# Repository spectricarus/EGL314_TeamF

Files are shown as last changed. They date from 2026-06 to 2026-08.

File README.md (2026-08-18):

# EGL314 Photobooth Project

This repository contains the Proof of Concept, MVP, and Final build
documentation and source files for the EGL314 Media Solutioning Project 1
photobooth project, built for **Project Phantom**.

The project is a self-contained digital photobooth system that combines
software, hardware, and enclosure design. The system uses a Raspberry Pi,
touchscreen display, USB webcam, OpenCV, and MediaPipe to capture a user
photo, remove the original background, replace it with a selected
background, and save the final output image. The components are contained inside a 3D-printed enclosure that is specially designed to properly mount a Raspberry Pi, a 7 inch touchscreen and a USB camera.

## How the software and hardware fit together

These are documented separately (different team members are responsible for
each), but they form one physical system:

- The **Raspberry Pi** runs the software in this repository directly —
  `finalV6.py` is the app that appears on the touchscreen.
- The **touchscreen display** is what the software's Tkinter GUI renders to.
- The **USB webcam**, mounted in the enclosure, is what the software reads
  from (`CAMERA_DEVICE` in `finalV6.py` points to it).
- The **enclosure** physically houses and positions the Pi, screen, and
  camera, and its cable routing/mounting design determines how those
  components are physically wired to each other.

## Repository Structure

```text
EGL314_TeamF/
├── README.md
├── POC/
│   ├── README.md
│   ├── CODE_STRUCTURE.md
│   ├── app.py
│   ├── style.py
│   ├── requirements.txt
│   ├── assets/
│   │   └── backgrounds/
│   ├── images/
│   └── Enclosure/
│       ├── README.md
│       ├── CAD/
│       ├── STL/
│       └── Images/
│
├── MVP/
│   ├── README.md
│   ├── Hardware/
│   └── Software/
│       ├── README.md
│       ├── finalV6.py
│       ├── style.py
│       ├── requirements.txt
│       ├── docs/
│       │   ├── CODE_STRUCTURE.md
│       │   ├── environment-setup.md
│       │   ├── dependencies.md
│       │   ├── file-connections.md
│       │   ├── pipeline-explained.md
│       │   ├── ui-flow.md
│       │   └── background-templates.md
│       └── assets/
│           ├── pipeline-diagram.svg
│           ├── screenshots/
│           └── background-templates/
│
└── Final/
    ├── README.md
    ├── Enclosure/
    │   └── README.md
    └── Software/
        ├── README.md
        ├── finalphotobooth.py
        ├── style.py
        ├── requirements.txt
        ├── docs/
        │   ├── environment-setup.md
        │   ├── dependencies.md
        │   ├── CODE_STRUCTURE.md
        │   ├── file-connections.md
        │   ├── pipeline-explained.md
        │   ├── ui-flow.md
        │   ├── background-templates.md
        │   ├── architecture.md
        │   ├── camera-reliability.md
        │   ├── download-pipeline.md
        │   ├── compositing-and-banner.md
        │   └── troubleshooting.md
        └── assets/
            ├── backgrounds/
            └── screenshots/
```

## Sections

### [`POC`](./POC)

The `POC` folder contains the software Proof of Concept for the photobooth
application — Python source code, required dependencies, and background
assets.

### [`Enclosure`](./POC/Enclosure)

Nested inside `POC`, this folder contains the physical enclosure design:
CAD files, STL files, images, and documentation for the Raspberry Pi,
touchscreen display, USB webcam, cable routing, and mounting system.

### [`MVP`](./MVP)

The `MVP` folder contains the working MVP version of the photobooth
application — the stage after Proof of Concept, split into two parts:

- [**Software**](./MVP/Software/README.md) — full documentation covering the
  code, dependencies, environment setup, a diagram of the background-removal
  pipeline and the reasoning behind it, and UI flow
- [**Hardware**](./MVP/Hardware) — enclosure and physical build for the MVP
  stage

### [`Final`](./Final)

The `Final` folder contains the finished, event-ready version of the
photobooth used for **Project Phantom** — the stage after MVP, with
reliability, performance, and experience improvements made in the final
stretch before the event.

See [`Final/README.md`](./Final/README.md) for the full picture, including
the hardware used and links into both the Software and Enclosure
documentation.

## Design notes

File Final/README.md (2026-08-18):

# Project Phantom Photobooth — Final Build

[↑ Back to repository overview](../README.md)

This is the final, event-ready version of the photobooth built for **Project Phantom** (NYP EGL314). It builds on the earlier POC and MVP stages, with a large number of reliability, performance, and experience improvements made in the final stretch before the event.

A guest walks up, gets their photo taken, sees themselves composited onto a themed background, picks their favourite, and scans a QR code to take it home — all through a touchscreen, with no need for anyone to touch a keyboard.

## Hardware — the shared foundation for both Enclosure and Software

This section lives here, at the top level, deliberately — it isn't really an "enclosure thing" or a "software thing," it's context both halves of this documentation depend on. The enclosure needs to physically fit around this exact hardware (cutout sizes, screw mounts, cable routing); the software is written assuming these exact components and their specific capabilities. If any of these get swapped for a different model later, both sides of the documentation may need re-checking against the real thing.

**Required:**

| Component | Notes |
|---|---|
| **Raspberry Pi 4 Model B** | The computer running everything |
| **Raspberry Pi 7" touchscreen display** | The official Raspberry Pi touchscreen — what the guest sees and taps |
| **Display ribbon cable** | Connects the touchscreen to the Pi — its length and routing is a real constraint on the enclosure's internal layout |
| **Logitech BRIO 4K USB webcam** | Takes the photo. The software is written around this specific camera's capabilities (resolution, supported frame rates) — see the [Software docs](./Software/docs/camera-reliability.md) for why the exact camera matters more than you'd expect |
| **DFRobot Gravity Digital Speaker Module (SKU: FIT0449)** | Plays the countdown beeps and confirmation sounds, wired to a GPIO pin on the Pi |
| **32GB microSD card** | Holds the OS and everything the software needs to run |
| **Jumper wires and power supply** | Wiring the speaker to the Pi, and powering the whole thing |

**Optional (improves photo quality, not required for the booth to function):**

| Component | Notes |
|---|---|
| **Two studio-style LED light panels with stands** | Gives even, flattering lighting on the guest. Any reasonably even light source works — dedicated panels just do it noticeably better than ambient room lighting alone |

**Also required, but not a physical component: a wifi connection.** The software uploads each finished photo to Google Drive and generates a QR code linking to it, so the guest can get the photo on their own phone — this requires an active internet connection at the point of upload. Without wifi, photos can still be taken and previewed, but the download/QR step won't work. See the [download pipeline docs](./Software/docs/download-pipeline.md) for how this upload actually works.

None of this is exotic hardware — it's a fairly standard "Raspberry Pi + touchscreen + webcam" kiosk setup, just with the specific models above.

## Where to go from here

This documentation is split into two parts, matching the two halves of the actual physical build, both of which build on the hardware above:

- **[Enclosure](./Enclosure/README.md)** — the physical housing/case the electronics live inside.
- **[Software](./Software/README.md)** — everything that makes the booth actually work: the code, how to set it up, and how it's built.

## A quick note on how this documentation works

Each section starts with a plain-language overview that assumes no prior knowledge — you should be able to read just the top of each page and understand what's going on and why. Further down, or linked out to separate pages, is more technical depth for anyone who wants it. You never *need* to click into the deeper pages to follow the main story — they're there if you're curious, not required reading.

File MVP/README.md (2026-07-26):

# MVP — Photobooth Project

This folder contains the MVP (Minimum Viable Product) submission, split into two
sections covering the two halves of the build:

- [**Software**](./Software/README.md) — the background-removal photobooth
- [**Hardware**](./Hardware/README.md) — the physical enclosure, mounting, and 3D-printed components

Jump straight to the section you need:

| Section | What's in it |
|---|---|
| [Software →](./Software/README.md) | Code, dependencies, environment setup, UI flow |
| [Hardware →](./Hardware/README.md) | Enclosure design, mounting, physical build |

---

This documentation is written with the intent that someone with no prior context on this
project (a "layman") can read it top to bottom and reproduce the result from scratch.

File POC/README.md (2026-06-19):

# EGL314 Photobooth POC Documentation

## 1. Project Context and Rationale

This project is a self-contained digital photobooth system designed for EGL314 Media Solutioning Project 1. The goal of the project is to build an interactive booth where users can take a photo, remove the original background, replace it with a selected digital background, and save the final output.

The project is relevant because modern photobooths are commonly used in events, studios, and social spaces. A good photobooth system should be simple to use, visually clear, and able to produce an output that users would actually want to keep. For the Proof of Concept stage, the focus is on proving that the main technical pipeline works before improving the full user experience for the next stage.

## 2. POC Objectives

The POC aims to demonstrate the following core functions:

1. Hardware integration between Raspberry Pi, touchscreen display, and USB webcam.
2. Live camera preview using OpenCV.
3. Background selection through a touchscreen-friendly interface.
4. Photo capture and retake flow.
5. Background removal using MediaPipe segmentation.
6. Background replacement using digital image templates.
7. Final image output saved as a 1920 × 1080 PNG.
8. Auto-delete function to remove saved photos after 15 minutes.

## 3. Research and Hypothesis

The POC uses OpenCV for camera capture and image processing because it provides direct webcam access and frame manipulation in Python. MediaPipe Selfie Segmentation is used because it can separate a human subject from the background using a machine-learning segmentation mask.

The main hypothesis is:

> If the Raspberry Pi can reliably capture a webcam image, generate a person segmentation mask, and composite the person onto a new background, then the core photobooth concept is technically feasible for further development.

During testing, lighting and image resolution were identified as important factors affecting background removal quality. Better lighting and higher camera resolution are expected to improve the segmentation result and final image quality.

## 4. System Overview

The POC system uses the following hardware:

* Raspberry Pi 4 Model B
* Raspberry Pi 7" touchscreen display
* Display ribbon cable for touchscreen connection
* USB webcam
* 32GB microSD card
* Jumper wires and power supply

The software stack includes:

* Python
* OpenCV
* MediaPipe
* NumPy
* Pillow
* Tkinter

## 5. Core Processing Pipeline

The POC follows this image-processing pipeline:

```text
USB Webcam
→ OpenCV camera capture
→ Live preview on touchscreen
→ User selects a background
→ User captures photo
→ MediaPipe generates segmentation mask
→ Mask is refined and smoothed
→ Person is composited onto selected background
→ Final 1920 × 1080 PNG is saved locally
→ Image is automatically deleted after 15 minutes
```

## 6. User Flow

The POC user flow is:

```text
Live Preview
→ Select Background
→ Capture Photo
→ Retake or Confirm
→ Process Background Removal
→ Save Final Image
→ Auto-delete after 15 minutes
```

This flow proves the main photobooth concept. The user can preview themselves, select a background, capture a photo, retake if needed, and confirm the final output.

## 7. POC Implementation

The main application is built using `app.py`, with UI settings separated into `style.py`.

### Main Files

| File / Folder | Purpose |
| --- | --- |
| `app.py` | Main photobooth application |
| `style.py` | UI colours, fonts, preview size, thumbnail size, and button styling |
| `requirements.txt` | Python package dependencies |
| `assets/backgrounds/` | Stores background image templates |
| `images/` | Stores hardware setup and connection reference images |
| `CODE_STRUCTURE.md` | Explains the source code structure and main functions |

For a more detailed explanation of the source code structure, main functions, and processing logic, refer to:

[POC Code Structure Documentation](./CODE_STRUCTURE.md)

## 8. Testing and Observations

The POC successfully demonstrated the main technical functions:

* USB webcam was detected and used for live preview.
* Photo capture worked through the touchscreen UI.
* MediaPipe was able to detect and segment the human subject.
* The selected background was applied to the captured image.
* The final output image was saved locally.
* Auto-delete logic was included to remove the image after 15 minutes.

Several technical and UX observations were identified during POC presentation:

* The UI works, but it can use the touchscreen screen space more effectively.
* Background removal quality depends heavily on lighting and camera quality.
* MediaPipe segmentation can struggle with hair, body edges, and multiple people.
* The current POC generates one output based on the selected background.
* The future version should allow the user to capture first, then choose from multiple generated background outputs.

## 9. Improvements Planned for Next Stage

The next stage will focus on improving the photobooth into a more polished MVP.

Planned improvements include:

1. Improved touchscreen layout with a larger live preview.
2. Countdown before photo capture.
3. Capturing at minimum 1920 × 1080 resolution.
4. Running MediaPipe once and reusing the mask across all backgrounds.
5. Processing all background options after the user confirms the captured photo.
6. Gallery view for all generated outputs.
7. Selecting one or multiple final images.
8. Download or QR code access for users.
9. Better background removal quality through improved lighting and mask tuning.

## 10. Conclusion

The POC proves that the main photobooth concept is technically feasible. The Raspberry Pi can capture an image from a USB webcam, process the image using MediaPipe, replace the background, and save the final output locally.

The next stage will focus on improving the user experience, output quality, background removal accuracy, and user download process.

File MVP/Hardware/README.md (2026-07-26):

# Hardware - Designing and 3D-printing the enclosure
[↑ Back to MVP overview](../README.md) (Software section is documented separately by teammate — linked from there)

This is the hardware half of the MVP: thought processes behind design decisions and STL files for 3D-printing

## What's in this folder

| File | What it is |
|---|---|
| [`CAD/back and front wall.dwg`](./CAD/back_and_front_wall.dwg) | AutoCAD drawing for the back and the front wall |
| [`CAD/base_(updated).dwg`](./CAD/base_(updated).dwg) | AutoCAD drawing for the base of the enclosure |
| [`CAD/side_walls.dwg`](./CAD/side_walls.dwg) | AutoCAD drawing for the side walls of the enclosure |
| [`CAD/top_cover.dwg`](./CAD/top_cover.dwg) | AutoCAD drawing for the top cover of the enclosure |
| [`STL/back-wall.stl`](./STL/back-wall.stl) | STL file for back wall of the enclosure |
| [`STL/base.stl`](./STL/base.stl) | STL file for base of the enclosure |
| [`STL/front-wall.stl`](./STL/front-wall.stl) | STL file for front wall of the enclosure |
| [`STL/side-wall-with-hole.stl`](./STL/side-wall-with-hole.stl) | STL file for the side wall of the enclosure with the power cable access hole |
| [`STL/side-wall.stl`](./STL/side-wall.stl) | STL file for side wall of the enclosure |
| [`STL/top.stl`](./STL/top.stl) | STL file for top cover of the enclosure |

## Designing the enclosure
When designing the enclosure, there were a few things to consider:
* Standoffs to mount the Raspberry Pi
* Mounting for a 7 inch Raspberry Pi touchscreen
* Mounting for USB camera
* Cable routing (eg. for power supply)
* Enclosure is able to be mounted on a tripod

## Images
To accommodate for these requirements, the design would include a front wall with "jailbars" to mount the touchscreen, standoffs on the base to mount the Raspberry Pi and a simple hole in the top cover where the USB camera will simply hang. The entire enclosure looks as such:
WhatsApp Image 2026-07-25 at 21 46 26 (1)

With Raspberry Pi mounting and screen mounting shown:
WhatsApp Image 2026-07-25 at 21 46 23 (1)

Enclosure mounted on tripod:
WhatsApp Image 2026-07-25 at 21 46 27 (3)

## Individual parts
The following images will show what each individual part of the enclosure would look like, including a brief description of special features, if any.

### Top cover
The top cover has a clearance hole for the USB camera to sit in and for the cable to pass through, as well as four bosses at each corner to make alignment of the top cover to the box easy.
WhatsApp Image 2026-07-25 at 21 46 16 (1)

### Front wall
The front wall has an opening the size of a 7-inch Raspberry Pi touchscreen and two "jailbars" that securely mount the screen itself.
WhatsApp Image 2026-07-25 at 21 46 15 (2)

### Back wall
The back wall has no special features.
WhatsApp Image 2026-07-25 at 21 46 16 (4)

### Left wall
The left wall has no special features.
WhatsApp Image 2026-07-25 at 21 46 02 (2)

### Right wall
The right wall has an opening to allow the power supply cable to reach the Raspberry Pi inside the enclosure.
WhatsApp Image 2026-07-25 at 21 46 02

### Base
The base has four standoffs that mount the Raspberry Pi, as well as a quarter inch screw hole at the bottom that mounts the tripod plate.
WhatsApp Image 2026-07-25 at 21 46 17 (3)WhatsApp Image 2026-07-25 at 21 46 19 (4)

## Possible improvements
* Mesh on the back wall to increase upload and download speed.
* Proper mount for USB camera instead of a hole.

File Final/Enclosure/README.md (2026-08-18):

# Enclosure — Photobooth Final Build

[↑ Back to Final overview](../README.md)

*This section covers the physical housing/case that the photobooth's electronics live inside — the design, the build process, and the reasoning behind it.*

**This section is maintained separately from the software documentation.** See the main [Final README](../README.md) for how this fits into the overall build.

---

## What's in this folder

| File | What it is |
|---|---|
| [`CAD/back and front wall.dwg`](./CAD/back_and_front_wall.dwg) | AutoCAD drawing for the back and the front wall |
| [`CAD/base_(updated).dwg`](./CAD/base_(updated).dwg) | AutoCAD drawing for the base of the enclosure |
| [`CAD/side_walls.dwg`](./CAD/side_walls.dwg) | AutoCAD drawing for the side walls of the enclosure |
| [`CAD/top_cover.dwg`](./CAD/top_cover.dwg) | AutoCAD drawing for the top cover of the enclosure |
| [`STL/back-wall.stl`](./STL/back-wall.stl) | STL file for back wall of the enclosure |
| [`STL/base.stl`](./STL/base.stl) | STL file for base of the enclosure |
| [`STL/front-wall.stl`](./STL/front-wall.stl) | STL file for front wall of the enclosure |
| [`STL/side-wall-with-hole.stl`](./STL/side-wall-with-hole.stl) | STL file for the side wall of the enclosure with the power cable access hole |
| [`STL/side-wall.stl`](./STL/side-wall.stl) | STL file for side wall of the enclosure |
| [`STL/top.stl`](./STL/top.stl) | STL file for top cover of the enclosure |

## Screw Specifications
18x 16mm M3 screws for the enclosure itself

4x 12mm M3 screws to mount the touchscreen to the front wall

4x 10mm M2.5 screws to mount the Raspberry Pi 4B to the base

---

## Images

### With Raspberry Pi mounting and screen mounting shown:
photo_6061915510594540163_y

---

### Enclosure mounted on tripod:
photo_6061915510594540162_y

---

## Individual parts
The following images will show what each individual part of the enclosure should look like.

### Top cover
photo_6061915510594540160_y

---

### Front wall
photo_6061915510594540157_y

---

### Back wall
photo_6061915510594540154_y

---

### Left wall
photo_6061915510594540152_y

---

### Right wall
photo_6061915510594540151_y

---

### Base
photo_6061915510594540150_y

---

### Base (including tripod mount)
photo_6061915510594540149_y

---

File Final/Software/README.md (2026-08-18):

# Software — Photobooth Final Build

[↑ Back to Final overview](../README.md)

This is the software half of the Final build: a Raspberry Pi kiosk app that captures a photo, removes the background automatically, lets the guest pick from several themed background templates, and delivers the final photo via a QR code — built on top of the MVP stage, with a large number of reliability and experience improvements made in the final stretch before the event.

## What's in this folder

| File / Folder | What it is |
|---|---|
| [`finalphotobooth.py`](./finalphotobooth.py) | The main application — everything runs from this one file |
| [`style.py`](./style.py) | Colours, fonts, and layout constants used throughout `finalphotobooth.py` |
| [`requirements.txt`](./requirements.txt) | Exact Python packages needed — `pip install -r requirements.txt` |
| [`assets/backgrounds/`](./assets/backgrounds) | The live background templates the app actually reads from |
| [`assets/screenshots/`](./assets/screenshots) | Screenshots referenced from `docs/ui-flow.md` |
| [`docs/environment-setup.md`](./docs/environment-setup.md) | Full from-scratch setup: OS, conda environment, camera, speaker, rclone |
| [`docs/dependencies.md`](./docs/dependencies.md) | Every library this project needs, and what each one is for |
| [`docs/CODE_STRUCTURE.md`](./docs/CODE_STRUCTURE.md) | Which file to run, and how `finalphotobooth.py` is organized internally |
| [`docs/file-connections.md`](./docs/file-connections.md) | How `finalphotobooth.py` and `style.py` connect, and how to actually run the app |
| [`docs/pipeline-explained.md`](./docs/pipeline-explained.md) | The background-removal pipeline, and why it's built this way |
| [`docs/ui-flow.md`](./docs/ui-flow.md) | Screen-by-screen walkthrough of the app |
| [`docs/background-templates.md`](./docs/background-templates.md) | Where template images live and how to swap them |
| [`docs/architecture.md`](./docs/architecture.md) | Why the app uses multiple background threads, and what runs where |
| [`docs/camera-reliability.md`](./docs/camera-reliability.md) | The biggest problem in the whole project — every approach tried, and what actually fixed it |
| [`docs/download-pipeline.md`](./docs/download-pipeline.md) | How photos get uploaded and turned into a QR code |
| [`docs/local-cleanup.md`](./docs/local-cleanup.md) | Why the old 15-minute auto-delete timer was removed, and how cleanup actually works now |
| [`docs/compositing-and-banner.md`](./docs/compositing-and-banner.md) | The event banner, and how it's layered onto each photo |
| [`docs/troubleshooting.md`](./docs/troubleshooting.md) | Known issues hit during development, and known accepted limitations |

## Quick start

If you just want to get the app running, read these in order:

1. [`docs/environment-setup.md`](./docs/environment-setup.md) — sets up the Pi from a blank state
2. [`docs/dependencies.md`](./docs/dependencies.md) — what's actually being installed and why
3. [`docs/CODE_STRUCTURE.md`](./docs/CODE_STRUCTURE.md) — which file to run and how it's organized
4. [`docs/file-connections.md`](./docs/file-connections.md) — how to actually launch it, plus quick troubleshooting

Everything else is reference material for understanding *why* things are built the way they are, not required just to run the app — [`docs/camera-reliability.md`](./docs/camera-reliability.md) in particular is worth reading if you want to understand the single biggest engineering problem this project ran into and how it was actually solved.

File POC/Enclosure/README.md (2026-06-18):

# EGL314 Photobooth Enclosure POC Documentation

## 1. Project Context

This enclosure was designed for the EGL314 Photobooth Project. The purpose of the enclosure is to house and protect the Raspberry Pi 4, touchscreen display, USB webcam, power cabling, and supporting hardware while maintaining portability and convenient assembly.

The enclosure is intended to be mounted onto a tripod, allowing the photobooth system to be deployed in various locations. The design must also allow access to power, USB connections, and future maintenance.

For the Proof of Concept (POC) stage, the focus is on demonstrating that the enclosure can physically accommodate all required components and that the major structural features can be successfully manufactured using 3D printing.

## 2. POC Objectives

The enclosure POC aims to demonstrate the following:

* Successful mounting of a Raspberry Pi 4 using standoffs
* Successful mounting of a touchscreen display
* Functional tripod mounting system
* Functional screw-based assembly system
* Space for cable routing
* 3D printable

## 3. Design Requirements

The enclosure must accommodate:

* Raspberry Pi 4
* Raspberry Pi touchscreen display
* USB webcam
* Power supply cable
* USB camera cable

The current enclosure design includes:

* M2.5 mounting points for the Raspberry Pi
* M3 mounting points for the touchscreen
* M3 assembly screws between enclosure panels
* Tripod mounting thread
* Removable top cover

## 4. Current Enclosure Dimensions

### Base

* Length: 220 mm
* Width: 130 mm
* Height: 40 mm

### Front Panel

* Length: 240 mm
* Height: 190 mm
* Thickness: 10 mm

### Back Panel

* Length: 240 mm
* Height: 190 mm
* Thickness: 10 mm

### Side Panels

* Length: 130 mm
* Height: 190 mm
* Thickness: 10 mm

### Top Cover

* Length: 220 mm
* Width: 150 mm
* Thickness: 10 mm

### Overall Enclosure

* 240 mm × 150 mm × 200 mm

## 5. Design Overview

The enclosure consists of six primary printed components:

1. Base
2. Front Panel
3. Back Panel
4. Left Side Panel
5. Right Side Panel
6. Top Cover

The top cover is removable to allow access to internal components.

## 6. Raspberry Pi Mounting System

The Raspberry Pi is mounted using four standoffs positioned according to the official Raspberry Pi 4 mounting pattern.

### Features

* Four M2.5 threaded mounting holes
* Elevated standoff design
* Clearance for underside components
* Space for power and USB cable routing

## 7. Screen Mounting System

The touchscreen is mounted using internal support bars positioned behind the front panel.

### Features

* Four M3 threaded mounting points
* Structural support bars

## 8. Tripod Mounting System

A threaded mounting hole is located at the centre of the base.

### Features

* Compatible with the project tripod mounting screw
* Placed in the center of the base for stability
  
The tripod mounting system allows the enclosure to be mounted without additional brackets.

## 9. Assembly System

The enclosure uses M3 screws for assembly.

### Assembly Sequence

1. Front panel attached to side panels
2. Back panel attached to side panels
3. Wall assembly attached to base
4. Internal components installed
5. Top cover attached

This approach simplifies maintenance and future upgrades.

## 10. Cable Routing

Cable routing space has been reserved for:

* Raspberry Pi power cable
* USB webcam cable
* Display connections

The routing design aims to minimise cable obstruction and improve internal organisation.

## 11. Manufacturing Status

### Completed

* Base printed
* Front panel printed

### Designed in CAD

* Back panel
* Side panels
* Top cover

### Generated Files

* DWG files
* STL files

## 12. Future Improvements

There were some problems with the design, such as there still being insufficient space for cables (e.g. not enough space for the USB camera's cable from the Raspberry Pi to the top of the enclosure). To solve this, I will be making the base longer so that there is sufficient space for the cable to run comfortably and seamlessly through the enclosure.
More improvements I plan to implement include:
* Reduced print time by making the walls thinner and to save 3D printing filament
* Improved camera mounting solution
* Final aesthetic refinements

## 13. Conclusion

The enclosure POC demonstrates that the major structural requirements of the photobooth system can be achieved through a modular 3D-printed design. The printed base and front panel validate the manufacturing approach, while the remaining CAD models establish the foundation for the MVP enclosure.

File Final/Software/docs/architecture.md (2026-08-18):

# Architecture: Why This App Uses Multiple Background Threads

## The problem this solves

A touchscreen app needs to feel responsive at all times — a guest tapping a button should get an immediate reaction, not a frozen screen. But this app also has to do several *slow* things: reading from a camera that can occasionally hang for several seconds, running an AI model that takes a few seconds per photo, and uploading a file over wifi that might be slow or flaky.

Python (and the graphical toolkit this app is built on, called Tkinter) normally runs everything on a single thread. If any single operation on that thread takes a while, *the entire app freezes* — not just the part that's slow, literally everything, including the ability to tap any button, while that one operation is running.

Early in development, this caused a specific, confusing set of bugs: things like the loading spinner not animating, or the settings button seeming completely unresponsive — which looked like separate problems, but were actually all the same root cause showing up in different places.

## The fix: background threads for anything slow

A **thread** is a way for a program to do more than one thing at once. This app moves every slow, unpredictable operation off the main thread and onto its own background thread, so the main thread — the one responsible for drawing the screen and responding to taps — is always free.

There are four background threads running during normal use:

1. **Camera reader thread** — continuously reads frames from the webcam in a loop. The main thread never talks to the camera directly; it just checks "what's the most recent frame this background thread has grabbed?" every fraction of a second. If the camera hangs for a moment, only this background thread is affected — the rest of the app keeps working.
2. **Photo processing thread** — the AI-based background removal (see [pipeline-explained.md](./pipeline-explained.md)) runs here, so the "Analyzing your photo..." screen can show a genuinely animating spinner instead of a frozen one.
3. **Upload thread** — uploading the finished photo and generating the QR code link happens here (see [download-pipeline.md](./download-pipeline.md)), for the same reason.
4. **Keep-alive thread** — periodically pings the upload system in the background to keep its connection warm, so the *next* upload doesn't have to pay a slow "reconnecting" cost.

## The one rule that makes this safe

Background threads are **never allowed to directly touch anything on screen**. Tkinter (the screen-drawing library) isn't designed to be touched from more than one thread at once — doing so causes crashes or corrupted screen state.

Instead, whenever a background thread finishes its work and needs to update the screen, it hands the result back to the main thread using a scheduling call (`root.after(0, ...)` in the code), which safely queues that update to happen on the main thread at the next opportunity. This is the pattern used consistently everywhere background threads interact with the screen.

## Why this mattered more than it might sound like

This wasn't a minor performance tweak — several real, previously mysterious bugs turned out to be the *same underlying issue* (something blocking the main thread) showing up in different disguises: a frozen loading spinner, an unresponsive settings button, camera capture appearing to hang. Once background threads were properly introduced for every slow operation, all of these were fixed by the same underlying change, not four separate patches.

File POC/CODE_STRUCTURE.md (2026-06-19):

# POC Code Structure Documentation

## Overview

The POC photobooth application is built using two main Python files:

| File | Purpose |
| --- | --- |
| `app.py` | Main application logic, user interface flow, camera preview, image capture, MediaPipe processing, background replacement, image saving, and auto-delete |
| `style.py` | UI colours, font settings, preview size, thumbnail size, and button styling |

The code is separated this way so that the main application logic remains in `app.py`, while visual styling and layout values can be adjusted in `style.py` without changing the core program logic.

---

## Folder Structure

```text
POC/
├── README.md
├── CODE_STRUCTURE.md
├── app.py
├── style.py
├── requirements.txt
├── assets/
│   └── backgrounds/
└── images/
```

### Folder Purposes

| Folder / File | Purpose |
| --- | --- |
| `app.py` | Runs the photobooth application |
| `style.py` | Stores interface colours, fonts, and sizing values |
| `requirements.txt` | Lists the required Python libraries |
| `assets/backgrounds/` | Stores the background image templates used by the photobooth |
| `images/` | Stores hardware setup and connection reference images |

Generated output images are created locally during runtime and are not committed to the repository.

---

## Main Application File: `app.py`

`app.py` contains the main photobooth program. It uses Tkinter for the touchscreen interface, OpenCV for USB webcam capture, MediaPipe for background segmentation, NumPy for image compositing, and Pillow for converting images into a Tkinter-compatible display format.

The main class is:

```python
class PhotoboothApp:
```

This class controls the full application, including:

* starting and stopping the camera
* displaying the live preview
* showing background thumbnails
* capturing a photo
* allowing retake or confirm
* processing the image
* saving the final output
* deleting saved images after 15 minutes

---

## Key Settings

At the top of `app.py`, the program defines important file paths and settings.

```python
BASE_DIR = os.path.dirname(os.path.abspath(__file__))
BACKGROUND_DIR = os.path.join(BASE_DIR, "assets", "backgrounds")
SAVE_FOLDER = os.path.join(BASE_DIR, "saved_images")
```

These settings make sure the app can locate its background images and save generated outputs in the correct folders.

The camera is set using:

```python
CAMERA_DEVICE = "/dev/video0"
```

This is used instead of a generic camera index because the Raspberry Pi may detect multiple video devices. Using `/dev/video0` makes the webcam path more specific and reliable.

The final output resolution is set to:

```python
OUTPUT_WIDTH = 1920
OUTPUT_HEIGHT = 1080
```

This ensures the generated image is saved as a 1920 × 1080 PNG.

The auto-delete timer is set to:

```python
AUTO_DELETE_MS = 15 * 60 * 1000
```

This deletes the final saved image after 15 minutes.

---

## Main User Flow

The POC application follows this user flow:

```text
Live Preview
→ Select Background
→ Capture Photo
→ Retake or Confirm
→ Process Image
→ Display Final Image
→ Auto-delete after 15 minutes
```

This flow proves the core photobooth concept by allowing the user to capture a photo, apply a selected background, and save the final image.

---

## Main Functions in `app.py`

### `load_backgrounds()`

This function loads all background images from:

```text
assets/backgrounds/
```

It supports:

```text
.jpg
.jpeg
.png
```

The images are sorted so that the backgrounds appear in a consistent order every time the app runs.

---

### `start_camera()`

This function starts the USB webcam using OpenCV.

```python
self.cap = cv2.VideoCapture(CAMERA_DEVICE, cv2.CAP_V4L2)
```

The camera preview is set to 640 × 480 for smoother and more reliable performance on the Raspberry Pi during the POC stage.

```python
self.cap.set(cv2.CAP_PROP_FRAME_WIDTH, 640)
self.cap.set(cv2.CAP_PROP_FRAME_HEIGHT, 480)
```

Although the preview is smaller, the final output image is resized and saved at 1920 × 1080.

---

### `stop_camera()`

This function stops the preview loop and releases the camera.

It is used when moving from the live preview screen to the captured image screen, and also when exiting the application.

---

### `delayed_start_camera()`

This function starts the camera after a short delay.

It was added to improve reliability when returning from the retake screen. Without the delay, the camera could sometimes lag or freeze when being reopened too quickly.

---

### `show_live_screen()`

This function displays the main live preview screen.

The screen includes:

* title
* instruction text
* live camera preview
* selected background label
* background thumbnail selector
* capture button
* exit button

The user selects a background first, then presses the capture button.

---

### `get_thumbnail_image()`

This function creates and caches thumbnail images for the background selector.

The thumbnail cache prevents the app from repeatedly loading and resizing image files from storage whenever the user selects a background.

This improves responsiveness on the Raspberry Pi and reduces UI freezing.

---

### `update_thumbnail_buttons()`

This function updates the visible background thumbnail buttons.

Only a few thumbnails are shown at a time to fit the 7-inch touchscreen layout. The selected background is highlighted using a yellow border and different button styling.

---

### `select_visible_background()`

This function changes the selected background when the user taps one of the visible background thumbnails.

It updates:

* selected background index
* selected background label
* thumbnail highlight state

---

### `previous_background_page()` and `next_background_page()`

These functions allow the user to move through the available background options using the left and right arrow buttons.

---

### `update_preview()`

This function continuously reads frames from the webcam and updates the live preview.

The frame is flipped horizontally using:

```python
frame = cv2.flip(frame, 1)
```

This makes the camera preview feel more natural, similar to a phone front camera or real photobooth mirror preview.

The frame is resized to fit the touchscreen preview area before being displayed in Tkinter.

---

### `capture_photo()`

This function stores the current camera frame as the captured image.

After capturing, the camera is stopped and the app moves to the confirmation screen.

---

### `show_confirm_screen()`

This function displays the captured still image and gives the user two choices:

```text
RETAKE
CONFIRM
```

* `RETAKE` returns the user to the live preview.
* `CONFIRM` starts the image processing step.

---

### `retake_photo()`

This function shows a short “Restarting camera...” message before returning to the live preview screen.

This improves stability because the Raspberry Pi needs a short delay before reopening the webcam.

---

### `process_and_save()`

This function handles the full image processing and saving flow.

It:

1. Shows a processing screen.
2. Checks that a photo has been captured.
3. Checks that background images exist.
4. Runs background removal and compositing.
5. Saves the final image.
6. Shows the final output screen.
7. Starts the 15-minute auto-delete timer.

The final file is saved into:

```text
saved_images/
```

---

### `remove_background_and_composite()`

This is the main image processing function.

It performs the following steps:

1. Resize the captured frame to 1920 × 1080.
2. Load and resize the selected background to 1920 × 1080.
3. Convert the image from BGR to RGB for MediaPipe.
4. Run MediaPipe Selfie Segmentation.
5. Generate a segmentation mask.
6. Smooth the mask using Gaussian blur.
7. Apply a threshold of `0.45`.
8. Composite the person onto the selected background.

The threshold value of `0.45` was used because it is slightly more generous than `0.50`, helping to include more of the person, hair, and shoulders.

The mask is blurred again to create smoother edges before compositing.

---

### `show_final_screen()`

This function displays the final generated image.

The screen includes:

* final image preview
* auto-delete message
* take another button
* exit button

---

### `auto_delete_saved_file()`

This function deletes the saved output image after 15 minutes.

This prevents old generated photobooth images from remaining permanently on the Raspberry Pi.

---

### `close_app()`

This function safely exits the application.

It:

* stops the camera
* cancels the auto-delete timer if needed
* closes the MediaPipe segmenter
* destroys the Tkinter window

---

## Style File: `style.py`

`style.py` stores the visual settings for the POC interface.

It includes:

* main background colour
* preview background colour
* text colours
* button colours
* selected thumbnail colour
* preview size
* thumbnail size
* font settings

This makes the UI easier to adjust without editing the main application logic.

For example, the preview size is controlled using:

```python
PREVIEW_WIDTH = 440
PREVIEW_HEIGHT = 248
```

The final saved output is still 1920 × 1080, even though the preview is smaller for touchscreen performance.

---

## POC Limitations

The POC successfully demonstrates the core technical pipeline, but several limitations were identified:

1. The UI works but can use the touchscreen screen space more effectively.
2. The user must select a background before taking the photo.
3. Only one final image is generated per capture.
4. Background removal quality depends heavily on lighting.
5. MediaPipe segmentation can struggle with hair, shoulders, and multiple people.
6. The live preview is kept at a lower resolution for reliability.
7. Download or QR code access is not implemented yet.

---

## Planned Improvements

Future improvements include:

1. Larger live preview using more of the 7-inch screen.
2. Countdown before capture.
3. Higher-resolution image capture.
4. Capturing first before choosing backgrounds.
5. Processing all background options after capture.
6. Running MediaPipe once and reusing the mask for all background outputs.
7. Gallery view for generated outputs.
8. Selecting one or multiple final images.
9. Download or QR code access.
10. Improved lighting and mask tuning for better background removal.

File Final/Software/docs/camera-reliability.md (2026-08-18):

# Camera Reliability: The Biggest Problem, and How It Was Actually Solved

This was, by a wide margin, the single most time-consuming problem in the entire project. It's documented in detail here because the *final* fix only makes sense in light of everything that was tried and ruled out first — and because "why is it built this way" is a completely reasonable question to ask about the eventual, simple-looking solution.

## The symptom

Intermittently, taking a photo would fail or hang — the countdown would finish, but the actual capture would stall, sometimes for several seconds, sometimes much longer, with the console showing repeated `select() timeout` errors from the camera driver.

## What was tried, and why each attempt wasn't the real fix

**Attempt 1: Add longer delays before reading from the camera.** The theory was the camera hardware just needed more time to "settle" after being opened or reconfigured. This helped somewhat, but the problem kept coming back — because it wasn't really about *how long* to wait, it was about *what specifically* was being waited for.

**Attempt 2: Suspect the high-resolution capture.** The app originally captured photos at a higher resolution (4K) than the live preview (1080p), switching the camera's resolution briefly for each photo and switching back afterward, on the theory that a higher-resolution source photo gives a cleaner final result. This seemed like a plausible suspect — but testing showed the 4K capture itself reliably worked; the problem was elsewhere.

**Attempt 3: Move the camera reading off the main thread.** This was a real, necessary fix — described in [architecture.md](./architecture.md) — and it solved a genuine, separate problem: the *entire app* freezing (not just the camera) whenever a camera read took a while. But it didn't fully solve the capture failures, because the actual photo-taking step still ran directly on the main thread, still blocking everything when it hit trouble.

**Attempt 4: Detect and recover from a "stuck" camera thread.** Even after moving continuous reading to a background thread, there was a separate edge case: if a single camera read *never returned at all* (a true hang, not just a slow one), that background thread could get permanently stuck, with no way to safely force-stop it (Python cannot cleanly kill a thread that's blocked inside a lower-level system call). The fix was to track when the last successful frame arrived, and if too long passed, treat the thread as dead and start a completely fresh one rather than trusting a thread that claims to be running but isn't producing anything. This is a real, valuable safety net — but it still wasn't *the* root cause of the original failures.

## The actual root cause

The breakthrough came from a single test: the failure happened on the *very first capture of a session*, with nothing else going on — no retake, no idle wait, nothing unusual. That ruled out every theory above, which all assumed the problem was tied to *timing* or *history*.

What was actually happening: **every single photo capture involved changing the camera's resolution** — switching from the 1080p live-preview stream to a 4K capture, then switching back. That resolution-change operation itself, on this specific camera and driver combination, had a real, ever-present chance of triggering the failure — regardless of how long anything had been running, regardless of retakes, regardless of anything else. It wasn't rare or edge-case-y; it was baked into every single photo.

## The fix

**Stop changing resolution at all.** The final photo is now simply a copy of whatever frame the live preview was already showing at the moment of capture — the same 1080p stream, no separate high-resolution grab, no resolution switch of any kind.

This has one real, deliberate trade-off: the final photo is 1080p instead of a higher-resolution capture. Given how much instability the resolution switch caused, and how consistently the fix eliminated it, this was judged the right trade — a reliably-working booth beats a marginally sharper photo that sometimes doesn't work at all.

This fix was validated by deliberately trying to break it — repeated rapid retakes, retaking after full processing, leaving the booth idle for long stretches — and it held up cleanly where every earlier version eventually failed.

## Why the earlier fixes are still in the code

Even though none of attempts 1–4 were *the* fix, they weren't wasted effort — each of them fixed a real, separate problem (the whole-app-freezing issue, the stuck-thread edge case) that would still exist even with resolution-switching removed. The final, reliable version is the combination of all of them together, not just the last one.

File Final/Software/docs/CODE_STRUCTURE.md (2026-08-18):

# Code Structure

Which file to run, and how `finalphotobooth.py` is organized internally.

## Which file to run

`finalphotobooth.py` — this is the entire application; everything runs from this one file. `style.py` holds colours/fonts and is imported directly into it (see [file-connections.md](./file-connections.md)).

## How the file is organized

The constants at the top of the file (camera settings, colours-by-reference to `style.py`, the event banner text, timing/threshold values) are grouped under a `SETTINGS` banner — this is the first place to look if you need to change something like the event banner text, a timing value, or which GPIO pin the speaker uses, without needing to understand the rest of the code.

Below that, everything lives inside one class, `PhotoboothApp`, split into clearly labelled sections (each marked with a `# ====` banner comment in the file, so you can jump to them by searching):

| Section | What's in it |
|---|---|
| `__init__` | Startup: opens the window, starts the rclone daemon, sets up the speaker, loads the AI models |
| **BASIC HELPERS** | Small reusable utilities — resizing images for display, building buttons/popups consistently |
| **CAMERA** | Opening the camera, the background reader thread, the loading spinner |
| **AUDIO** | The three sound effects (countdown beep, capture sound, success chime) |
| **SCREEN 1: LIVE PREVIEW + CAPTURE** | The starting screen, the countdown, triggering a capture |
| **SCREEN 2: CAPTURED STILL + RETAKE / PROCEED** | The review screen after taking a photo |
| **SCREEN 3: PROCESSING** | Background removal and compositing against each theme |
| **SCREEN 4: OUTPUT GALLERY** | Browsing and selecting finished photos |
| **SCREEN 5: DOWNLOAD (ZIP → RCLONE → QR)** | Uploading and generating the QR code |
| **ERROR / AUTO DELETE / EXIT** | The error screen, local file cleanup, and shutdown |

Outside the class, at the very bottom of the file, is `fix_system_clock()` (corrects the Pi's clock at every startup — see [troubleshooting.md](./troubleshooting.md)) and the actual entry point that starts the app.

## If you're trying to find something specific

- **Change what the booth says or how it looks** → `SETTINGS` at the top, or `style.py`
- **Something camera-related is acting up** → the **CAMERA** section, and read [camera-reliability.md](./camera-reliability.md) first — this was the single biggest source of bugs in the whole project, and the reasoning behind how it's built now matters more than the code alone shows
- **Something about uploads/QR codes** → **SCREEN 5**, and [download-pipeline.md](./download-pipeline.md)
- **How the actual background-removal works** → [pipeline-explained.md](./pipeline-explained.md), which walks through it independent of the code

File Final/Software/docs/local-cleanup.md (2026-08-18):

# Local File Cleanup: Why the 15-Minute Timer Was Removed

## What needs to happen

Every photo session writes files to the Pi's local storage — the composited photos themselves, and the QR code image generated for download. Left unmanaged, these accumulate indefinitely across a whole event's worth of guests. Something needs to clean them up.

## The original approach, and the real bug that killed it

The first version scheduled a 15-minute timer per session: take a photo, and 15 minutes later that session's files would be automatically deleted, on the Pi and on Google Drive.

In practice, this had a genuine, fairly deep bug. The timer read *whichever session folder happened to be currently active* at the moment it fired — not necessarily the one it was originally scheduled for. If a new photo was taken within that 15-minute window (extremely likely at a real, busy event), the old timer would eventually fire and delete the *new*, currently-active session instead of the one it was actually meant to clean up. On top of that, the QR code images lived in a separate folder that this cleanup never touched at all, so they piled up indefinitely regardless. And separately, closing the app was found to only *cancel* the pending timer — which does not delete anything, it just prevents the scheduled deletion from ever happening. None of this was a single simple bug; it took several rounds of genuine debugging to fully understand.

## The fix: no timers at all

The current approach is much simpler, and was chosen specifically because it avoids all of the above by construction: **the local output folders are wiped completely — deleted and recreated empty — at both app startup and app shutdown.** No per-session tracking, nothing scheduled, nothing that can point at the wrong session because nothing is waiting on a clock in the first place.

This is also **crash-safe in a way the timer approach never was**: even if the app crashes or gets force-closed and never reaches a clean shutdown, the *next* time it starts, the startup wipe still clears out whatever was left behind before the new session begins. There's no window where stale files can accumulate indefinitely from a bad exit.

## What actually gets wiped, and what doesn't

- **`saved_images/`** (the finished photos) and **`qrcodes/`** (the generated QR code images) — both wiped on the Pi, automatically, at every startup and shutdown.
- **The uploaded copy on Google Drive is deliberately left alone.** There's no code that touches it at all — it's cleaned up manually, by whoever's running the booth, whenever they choose to. This was a deliberate simplification: earlier auto-delete-from-Drive logic added real complexity for a problem (Drive storage filling up) that isn't especially urgent compared to keeping the Pi's own local storage tidy between guests.

If you need to clear out old uploads, that's a manual step in Google Drive itself — nothing in the app will do it for you.

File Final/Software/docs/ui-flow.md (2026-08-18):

# UI Flow

[← Back to Software README](../README.md)

**Note: Camera covered for privacy reasons**

## 1. Live Preview

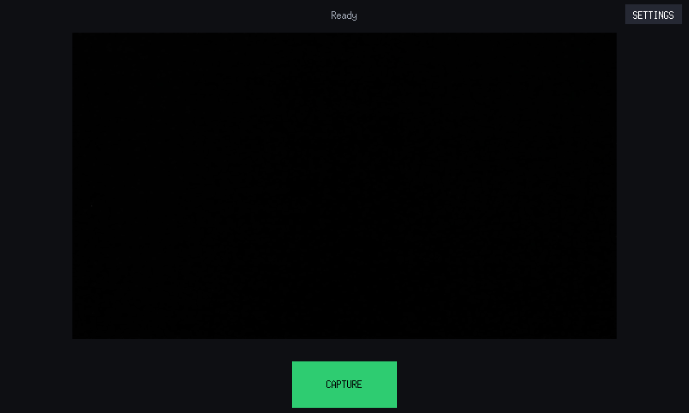
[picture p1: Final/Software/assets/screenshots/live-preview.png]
screenshot: live-preview.png


Continuous camera preview. Status text sits along the top of the screen. The
**CAPTURE** button stays disabled — showing an animated spinner instead —
until the camera is confirmed to be genuinely delivering frames, not just
"turned on" (see [camera-reliability.md](./camera-reliability.md) for why
that distinction matters). Pressing **CAPTURE** starts a 3-2-1-0 countdown
overlaid on the live feed, with a beep on each number; the photo is taken
automatically the moment it reaches zero, using a distinct capture sound
in place of a fourth beep.

## 2. Capture Review

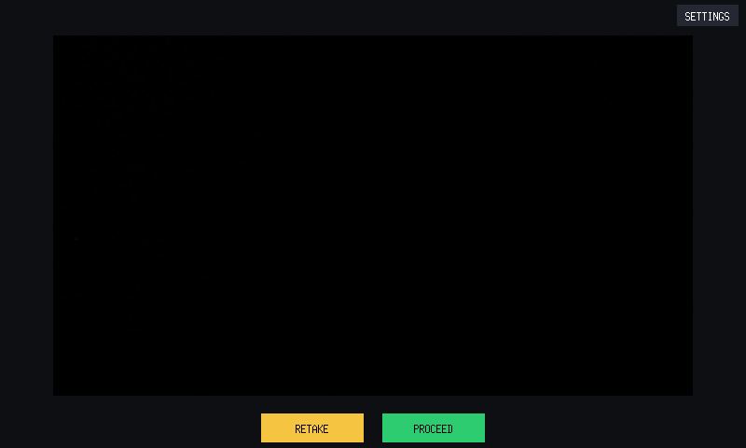
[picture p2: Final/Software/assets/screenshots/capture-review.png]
screenshot: capture-review.png


Shows the just-captured photo before any processing happens, so the user
can catch an obviously bad shot early. **RETAKE** returns to the live
preview to try again — instantly, with no reload delay, since the camera
is deliberately kept running in the background through this whole screen
rather than being closed and reopened. **PROCEED** sends the photo into
the background-removal pipeline.

## 3. Processing

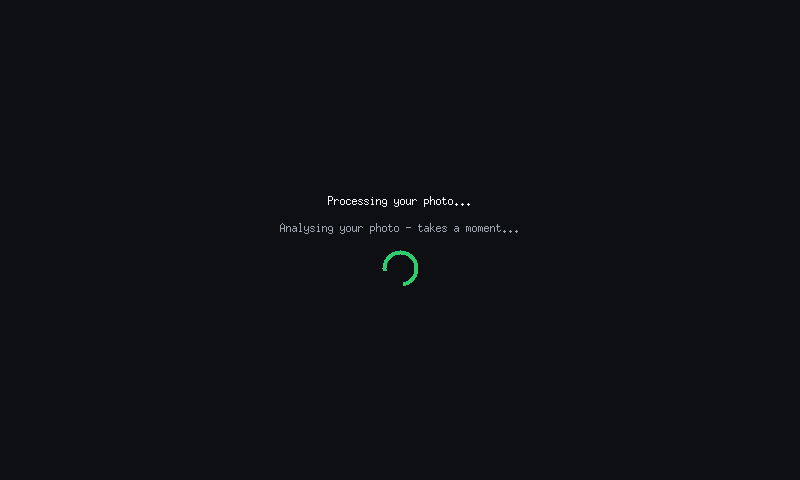
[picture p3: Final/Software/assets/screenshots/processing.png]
screenshot: processing.png


The first, unpredictable-duration stage: YOLO finds each person and
MediaPipe computes the background-removal mask (see
[pipeline-explained.md](./pipeline-explained.md) for the full pipeline).
Shown with an animated spinner, since this stage's duration can't be known
in advance — there are no progress bars anywhere in the app, a bar implies
a real percentage that doesn't genuinely exist here.

## 4. Applying Backgrounds

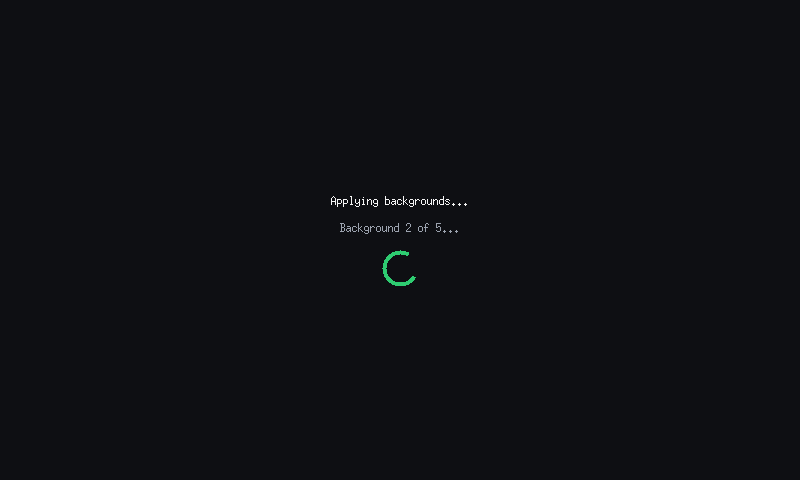
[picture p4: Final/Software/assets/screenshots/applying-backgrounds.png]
screenshot: applying-backgrounds.png


Once the mask above is computed, it's reused to composite the photo onto
every background template in turn — the mask itself is only calculated
once, not recalculated per template. Status text updates to "Background X
of Y" as each one completes, still with the same animated spinner.

## 5. Gallery

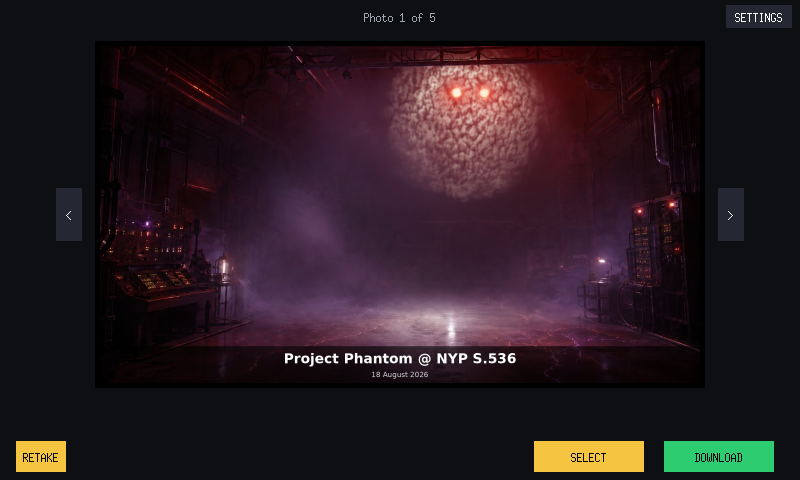
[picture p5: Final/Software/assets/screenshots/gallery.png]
screenshot: gallery.png


Every generated background variant, with:

- **Left/right arrows** to browse between templates
- Status text along the top showing position (e.g. "Photo 1 of 5")
- **Tap the photo itself, or the SELECT button**, to select it — the
  button dynamically relabels to **UNSELECT**, and tapping either the photo
  or the button again removes the selection
- **RETAKE** — in case the final composited result doesn't look good, not
  just the original photo (returns to live preview, discarding this
  session's output)
- **DOWNLOAD** — proceeds once at least one photo is selected

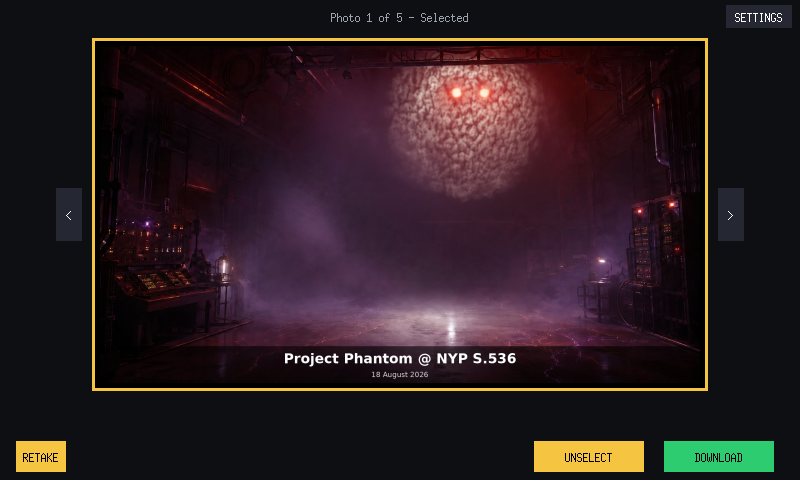
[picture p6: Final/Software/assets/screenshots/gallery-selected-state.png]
screenshot: gallery-selected-state.png


— a template shown in its selected state

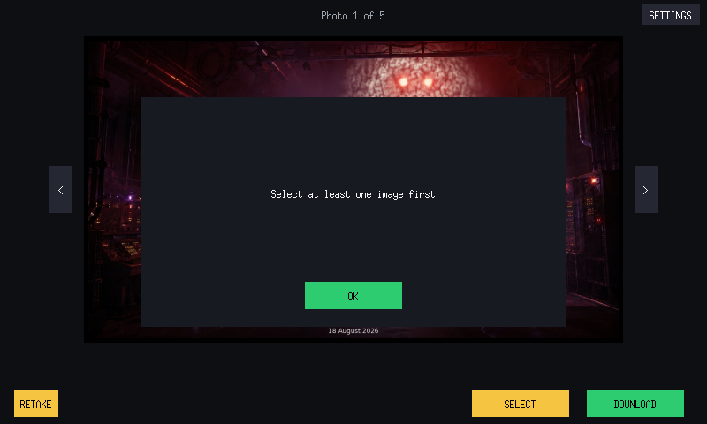
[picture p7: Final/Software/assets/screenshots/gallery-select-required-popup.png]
screenshot: gallery-select-required-popup.png


— the popup shown if DOWNLOAD is pressed with nothing selected

## 6. Preparing Your Download

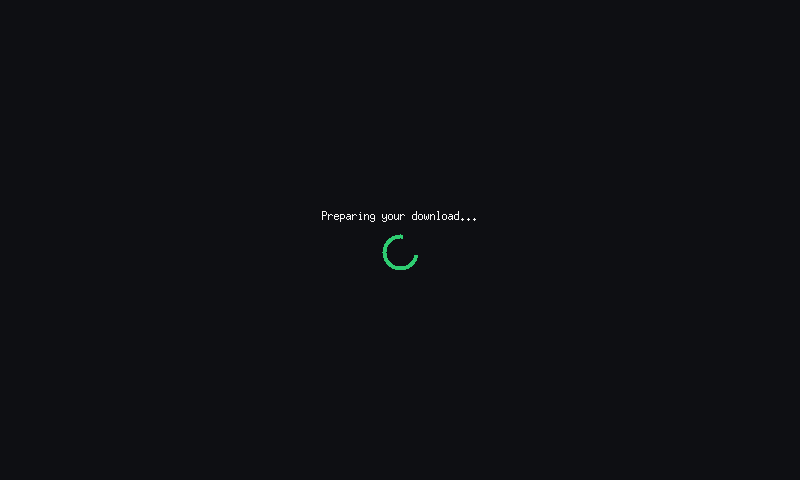
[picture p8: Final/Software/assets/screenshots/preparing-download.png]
screenshot: preparing-download.png


Only zips the selected photos if more than one was picked — a single
selected photo uploads directly, no zip step. Uploads via a persistent
`rclone` background service for speed, with an automatic fallback to a
slower-but-proven direct method if that service doesn't respond (see
[download-pipeline.md](./download-pipeline.md)). If that fallback kicks
in, a "taking longer than usual" message appears on this screen so it's
clear something is happening, not that the booth has frozen.

This step also depends on the Pi's system clock being genuinely correct —
see the time-sync note in [troubleshooting.md](./troubleshooting.md) if
this screen ever fails with a certificate/time-related error (the app
corrects the clock automatically at every startup, so this should be rare).

## 7. QR Download

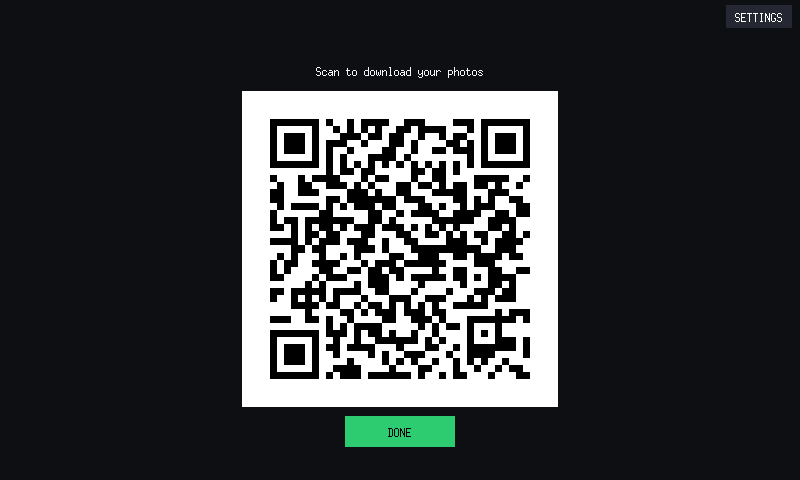
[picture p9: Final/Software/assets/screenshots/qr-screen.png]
screenshot: qr-screen.png


Shows a QR code generated from the uploaded photo's share link. Scanning it
with a phone starts the download immediately — no shared Wi-Fi required.
**DONE** returns to the live preview screen.

Unlike earlier stages of this project, there's no timed auto-delete for the
uploaded copy — the local session folder is wiped automatically (see
[local-cleanup.md](./local-cleanup.md) for the full story, including a real
bug the old timer-based approach had), but the uploaded copy on Google Drive is left
in place and cleaned up manually rather than on a timer.

## Settings

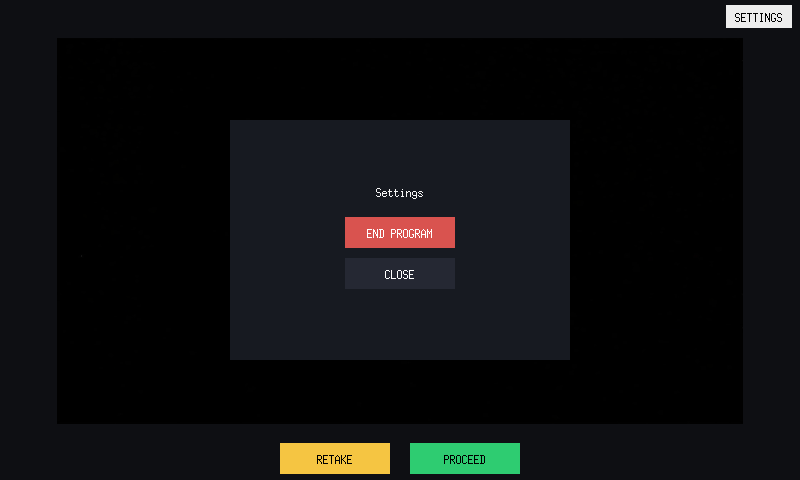
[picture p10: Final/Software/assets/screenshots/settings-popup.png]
screenshot: settings-popup.png


A settings button appears on most screens. Opens a small popup with
**END PROGRAM** and **CLOSE** — intentionally minimal, since this is a
kiosk app with no user-facing configuration needed.

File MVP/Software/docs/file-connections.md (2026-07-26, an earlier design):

# How the Files Connect & How to Run It

[← Back to Software README](../README.md)

## The two files

- **`finalV6.py`** — the entire application. All logic, all screens, the full
  background-removal pipeline, camera handling, and the download/QR flow live
  in this one file.
- **`style.py`** — a small file of constants only: colors (e.g. `BG_COLOR`,
  `CAPTURE_COLOR`), fonts (e.g. `TITLE_FONT`, `BUTTON_FONT`), imported at the
  top of `finalV6.py` with:

  ```python
  from style import (
      BG_COLOR,
      PANEL_COLOR,
      TEXT_COLOR,
      ...
  )
  ```

  It exists purely to keep the visual styling in one place, separate from the
  application logic — if you want to re-theme the app (different colors,
  different fonts), this is the only file you need to touch.

Both files must be in the **same folder** for the `import` to work.

## Folder structure the app expects at runtime

```
photobooth/
├── finalV6.py
├── style.py
├── assets/
│   └── backgrounds/       ← background template images go here
├── saved_images/          ← created automatically, holds each session's output
├── qrcodes/               ← created automatically, holds generated QR codes
```

The `assets/backgrounds/` folder needs to exist with at least one image in it
before the app can generate any output — see
[`background-templates.md`](./background-templates.md).

## Running the app

```bash
conda activate photobooth_usb
cd ~/photobooth
DISPLAY=:0 python finalV6.py
```

The `DISPLAY=:0` part is necessary if you're running this over SSH/PuTTY
rather than directly on the Pi's own desktop — it tells the app which physical
screen to draw the GUI on.

## Troubleshooting: download fails with a certificate/time error

If the download step fails and the Pi's system clock isn't actually synced
(check with `timedatectl status`), force it manually:

```bash
sudo apt install ntpdate -y
sudo ntpdate -u time.google.com
```

If that fails too (some networks block NTP traffic specifically), fall back to
setting the time from a normal HTTPS request instead, which almost never
gets blocked:

```bash
sudo date -s "$(curl -sI https://google.com | grep -i '^date:' | cut -d' ' -f2-)"
```

## Troubleshooting: camera fails to open

```bash
ls /dev/video*
```

If your camera isn't at `/dev/video0`, update the `CAMERA_DEVICE` constant
near the top of `finalV6.py` to match the correct path.

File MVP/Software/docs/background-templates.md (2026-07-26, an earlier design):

# Background Templates

[← Back to Software README](../README.md)

## Where they live

Background template images go in:

```
photobooth/assets/backgrounds/
```

Every image file in this folder is automatically loaded by the app at
startup and offered as a background option in the Gallery screen — there's
no code change needed to add or remove templates, just add or remove image
files in this folder.

## The templates used for this MVP

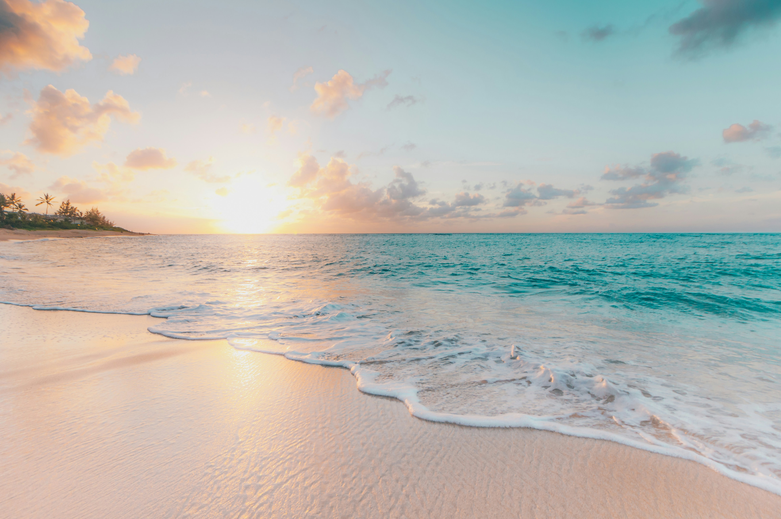
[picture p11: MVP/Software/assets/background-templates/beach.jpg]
> - `beach.jpg` — 
> - `city.jpg` — thumbnail
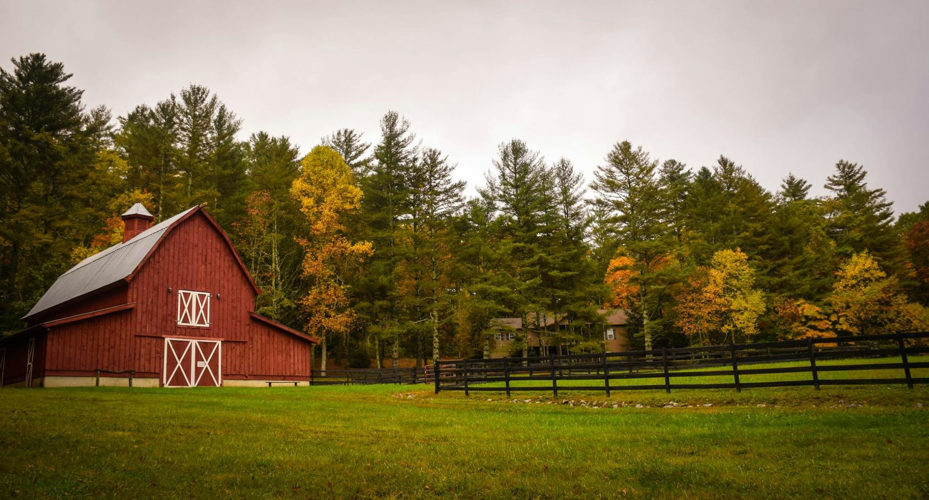
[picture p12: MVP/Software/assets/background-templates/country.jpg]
> - `country.jpg` — 
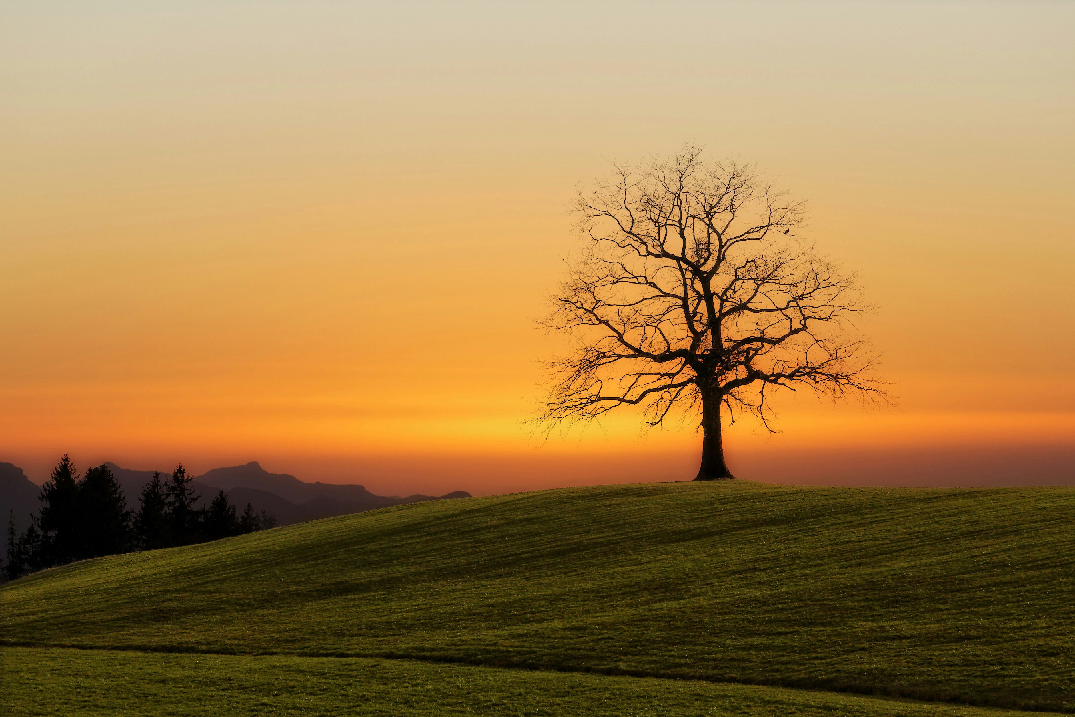
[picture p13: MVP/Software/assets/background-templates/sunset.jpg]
> - `sunset.jpg` — 

## These can be changed to anything

The specific templates used for this MVP are not fixed requirements of the
system — any JPEG or PNG placed in `assets/backgrounds/` works. Recommended
for best results: reasonably high resolution (the app composites at
1920×1080), and avoid extremely busy/high-detail backgrounds if hair-edge
quality matters, since fine detail is naturally easier to see clearly
against a smoother background.

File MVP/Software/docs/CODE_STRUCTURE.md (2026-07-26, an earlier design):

# Code Structure

[← Back to Software README](../README.md)

## Which file to run

```bash
DISPLAY=:0 python finalV6.py
```

`finalV6.py` is the only file you execute directly. `style.py` is imported
by it automatically and never run on its own.

## File responsibilities

| File | Responsibility |
|---|---|
| `finalV6.py` | Everything: GUI screens, camera handling, the background-removal pipeline, the download/QR flow. One file, no other custom modules. |
| `style.py` | Colors and fonts only — imported constants, no logic. |

See [`pipeline-explained.md`](./pipeline-explained.md) for the visual diagram
and full reasoning behind the background-removal pipeline specifically.

## `finalV6.py` internal structure

The file is organized top-to-bottom in this order:

1. **Imports and constants** — library imports, tunable values (resolution,
   thresholds, timing), and `style.py` imports
2. **`PhotoboothApp` class `__init__`** — loads YOLO and both MediaPipe
   models once at startup (not per-photo — see below for why that matters),
   sets up the window
3. **Basic helpers** — shared UI utilities (buttons, popups, screen clearing)
4. **Camera** — opening/closing the webcam, starting/stopping the live feed
5. **Screen 1: Live Preview + Capture** — the countdown and photo capture logic
6. **Screen 2: Capture Review** — retake/proceed after taking the photo
7. **Screen 3: Processing** — this is where the actual background-removal
   pipeline runs (see [`pipeline-explained.md`](./pipeline-explained.md))
8. **Screen 4: Gallery** — browsing/selecting generated background variants
9. **Screen 5: Download** — zip, `rclone` upload, QR code generation
10. **Error handling / auto-delete / exit** — cleanup logic, including the
    15-minute auto-delete timer for local files and the uploaded Drive copy

Each section is marked with a comment banner in the file itself
(`# ===== SCREEN N: ... =====`), so you can jump to the relevant part
directly by searching for the section name.

## Why models are loaded once at startup, not per photo

`self.yolo_model`, `self.segmenter` (landscape MediaPipe), and
`self.segmenter_general` (general MediaPipe) are all created once in
`__init__` and reused for every photo taken during the whole session.
Loading a model is comparatively slow; running inference on an
already-loaded model is fast. Re-loading any of these per photo would make
every single capture noticeably slower for no benefit.

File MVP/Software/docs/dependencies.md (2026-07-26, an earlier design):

# Dependencies & Libraries

[← Back to Software README](../README.md)

Every external library this project uses, and what it's actually responsible for.

| Library | What it's for |
|---|---|
| **mediapipe** | Provides `SelfieSegmentation` — the core model that separates a person from the background. Used twice in this project with two different settings: once tuned for full-body framing, once tuned for close-up framing (specifically for refining hair). |
| **ultralytics** (YOLO) | Provides YOLO11n, used purely for *detecting where each person is* in the photo (bounding boxes only, not segmentation). This is what makes the app handle group photos reliably — see [`pipeline-explained.md`](./pipeline-explained.md) for why. |
| **opencv-python** (`cv2`) | Camera capture, image resizing/cropping, color space conversion, and general image processing throughout the pipeline. |
| **numpy** | Array/matrix math underlying the alpha-mask blending logic — combining masks from multiple people, feathering edges, etc. |
| **Pillow** (`PIL`) | Image format conversion between OpenCV's format and what other libraries (like the YOLO/MediaPipe interfaces) expect. |
| **qrcode** | Generates the QR code shown on the download screen, from the Google Drive share link. |
| **tkinter** | Built into Python already — the GUI framework the entire touchscreen interface is built with. No separate install needed. |
| **rclone** (not a Python library — a separate command-line tool) | Uploads the selected photos to Google Drive and generates the shareable link used for the QR code. Called from the app via `subprocess`. |

## Why some things were tried and removed

A few libraries appear in earlier development but are **not** part of the
final app, worth knowing if you see references to them in old commits or
notes:

- **rembg** — tested extensively for background removal quality, ultimately
  not used in the final version (too slow, and gave inconsistent results on
  identical input across repeated runs)
- **pymatting** — tested for true alpha matting (a formal mathematical
  technique for soft edges), ultimately not used — MediaPipe's own native
  output, used correctly, turned out simpler and equally good

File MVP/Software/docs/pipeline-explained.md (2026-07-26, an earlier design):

# The Background-Removal Pipeline, Explained

[← Back to Software README](../README.md)

## The problem this solves

A single AI segmentation model works well for one person, close to the
camera. It breaks down in two specific ways: **group photos**, and **fine
detail like hair**. Rather than one model trying to do everything, this
pipeline splits the job across tools based on what each is actually good at.

## The pipeline, step by step

Pipeline diagram

Text version of the same flow:

```
Capture (4K attempt → 1080p output)
    ↓
YOLO11n → bounding box per person (detection only, +18% padding margin)
    ↓
For each person's crop:
    MediaPipe (landscape model) → soft body alpha
        ↓
    Find ambiguous sub-regions within that crop (hair, hand edges)
        ↓
    Each ambiguous region re-run through MediaPipe (general/selfie model)
        ↓
    Blended back in with feathered edges and a capped influence
    ↓
Merge all people into one full-frame mask
    ↓
Remove small disconnected noise specks
    ↓
Composite: paste ORIGINAL pixel colors directly using final alpha
```

## Why YOLO, and specifically why detection (not segmentation)

MediaPipe alone struggles with group photos because it's trained mostly on
close-up, single-person "selfie" framing — a wide 10-person shot is far
outside what it actually knows. YOLO11n finds each person's bounding box
first, which lets MediaPipe process each person as an individual close-up
crop instead of the whole wide scene at once.

Only the **detection** variant of YOLO is used (`yolo11n.pt`, not
`yolo11n-seg.pt`) — YOLO only needs to answer "where is each person," not
produce a precise silhouette. MediaPipe, tuned specifically for edge quality,
handles the actual masking once it has a clean, cropped view of one person.
A segmentation-capable YOLO model was tested and worked, but added real cost
(a heavier model, plus needing a separate matting step for hair quality) for
a job the lighter detection model already solves.

Each detected box is expanded by about 18% before cropping — a margin set by
observation during testing (what was getting clipped), not derived from a
formula — so hair sticking up past the top of the box, or feet at the
bottom, don't get cut off by a too-tight crop.

## Why two different MediaPipe configurations

MediaPipe's `SelfieSegmentation` has two settings tuned for different framing
distances:

- **Landscape** (`model_selection=1`) — tuned for a subject with more
  surrounding context. Used for each person's overall body mask.
- **General/selfie** (`model_selection=0`) — tuned for close, tightly-framed
  subjects. Used *only* to refine small regions where the landscape model's
  own confidence is ambiguous — mainly hair.

This split was decided from a direct A/B test on a real cropped photo: the
general model was noticeably better right at the hairline, but let more
background bleed through everywhere else on the body. That's the tradeoff
you'd expect — a more permissive model helps fine translucent detail but
hurts a confident, hard silhouette edge. Using landscape for the body and
confining general to only the small ambiguous regions gets the hair
improvement without paying that cost across the whole photo.

## Why the composite doesn't fade or shift color

The final image pastes the **original captured photo's pixel colors**
directly, using the computed alpha mask — no color re-estimation happens
anywhere. This was a deliberate choice after testing an approach (rembg's
built-in alpha matting) that *did* re-estimate colors in uncertain regions,
which caused the composited image to visibly fade depending on which
background template it was placed against. Direct pixel-paste avoids that
entirely.

## What was tried and rejected along the way

See [`dependencies.md`](./dependencies.md) for the short version. In brief:
reference-background subtraction (too fragile to camera auto-exposure
shifts, measured directly), rembg (best hair quality of anything tested, but
slow and gave inconsistent results on identical input), MediaPipe's
multiclass segmenter (best specifically at hair, but misclassified real
content like a shirt's printed graphic), and true alpha matting via
`pymatting` (a real, working technique, but could hang on numerically
unstable small regions — and testing showed the simpler two-MediaPipe-model
approach was equally good without that risk).

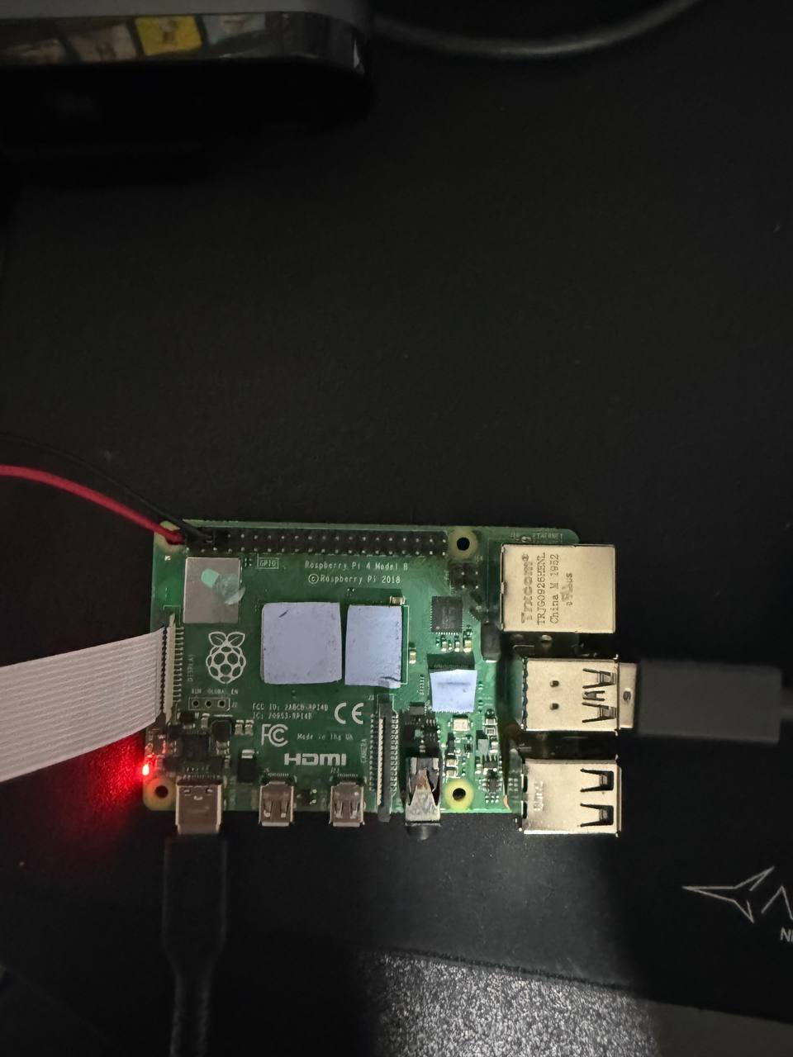
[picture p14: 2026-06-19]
POC/images/overview1.jpg

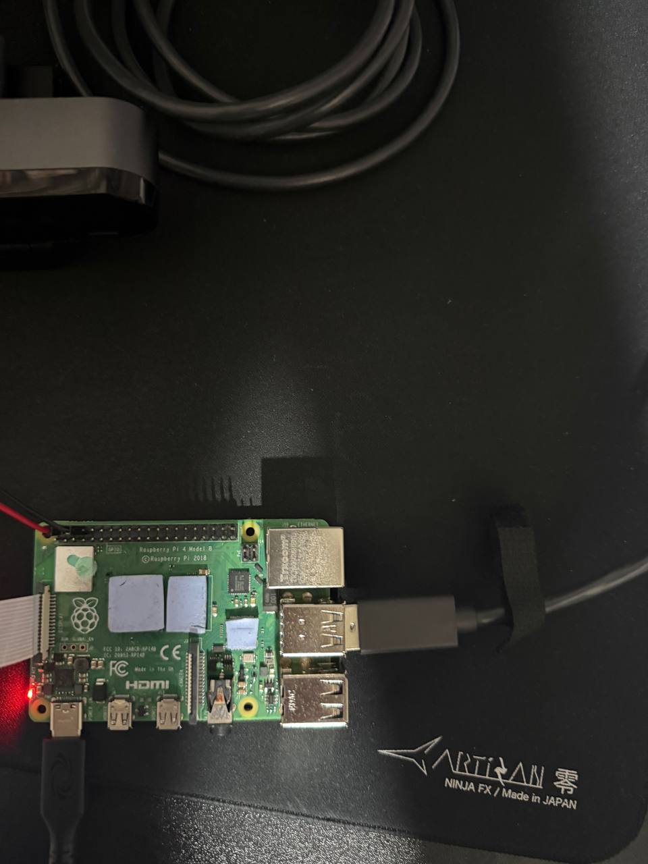
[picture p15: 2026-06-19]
POC/images/overview2.jpg

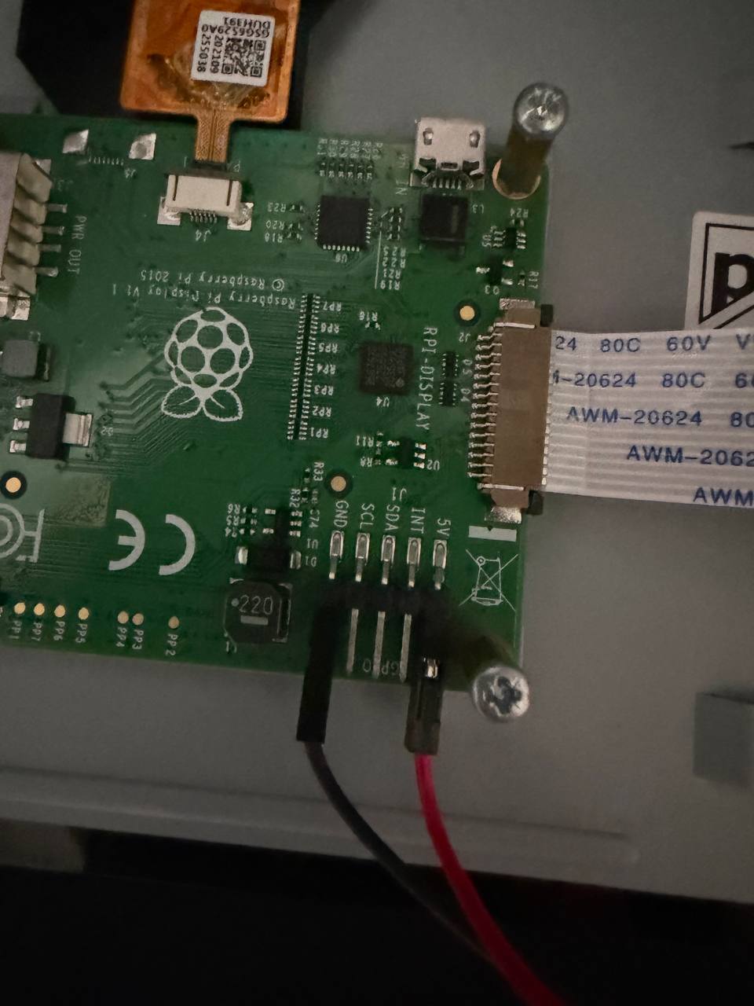
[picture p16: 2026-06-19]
POC/images/touchscreen_connections.jpg

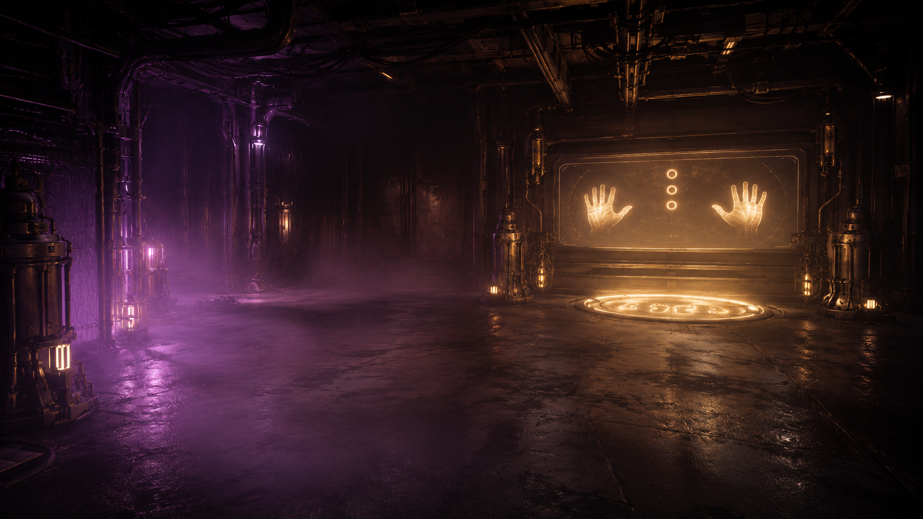
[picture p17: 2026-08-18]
Final/Software/assets/backgrounds/#4.png

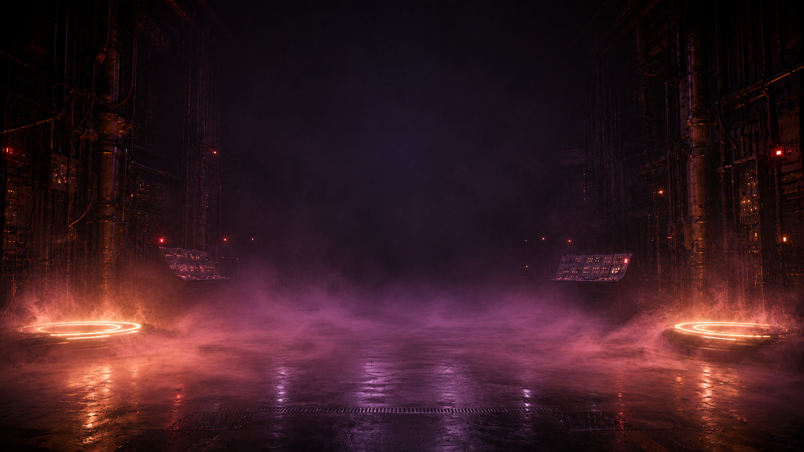
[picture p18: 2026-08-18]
Final/Software/assets/backgrounds/#2.png

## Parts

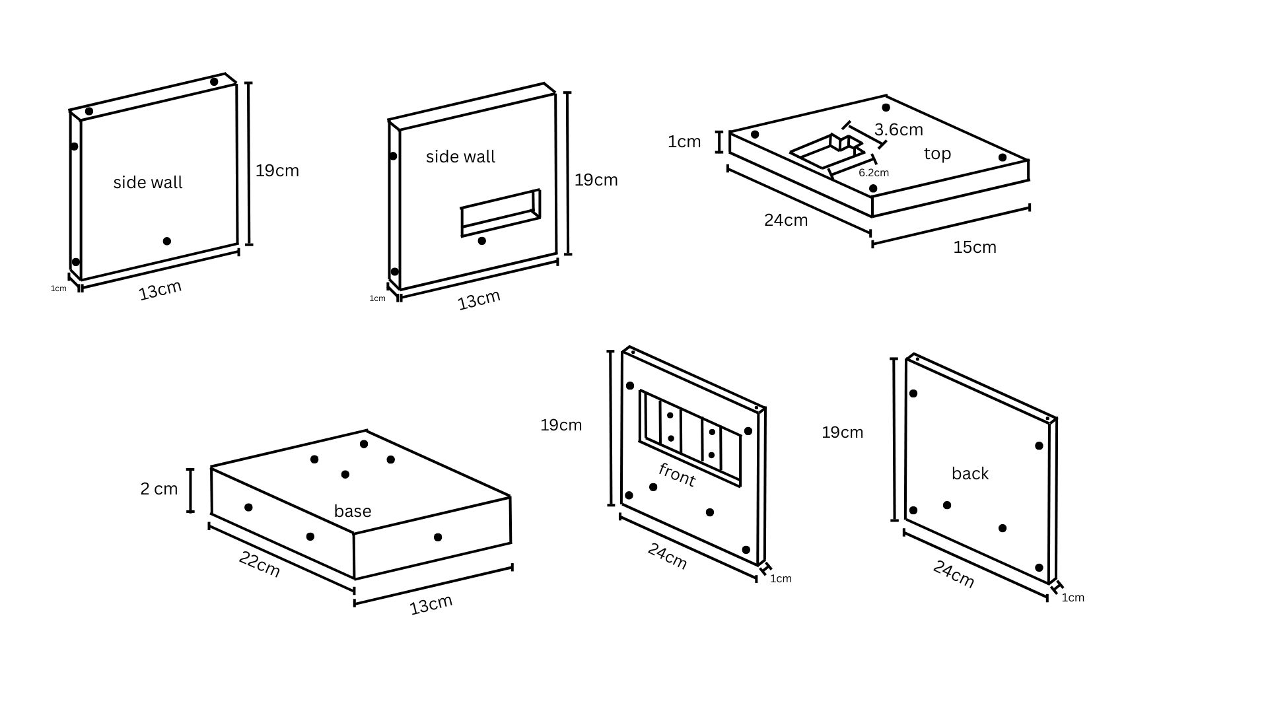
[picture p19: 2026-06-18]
POC/Enclosure/POC/Images/parts.jpg

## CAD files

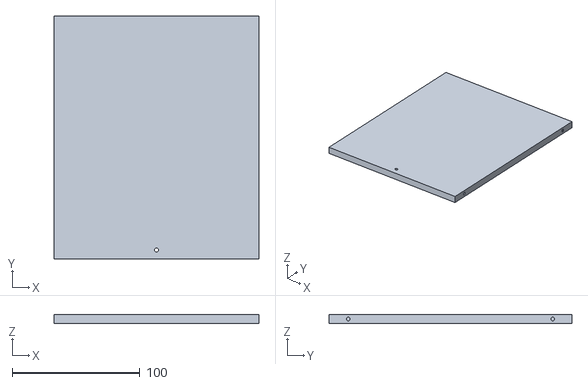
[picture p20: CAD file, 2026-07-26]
Final/Enclosure/STL/side-wall.stl
160.0 x 190.0 x 7.00

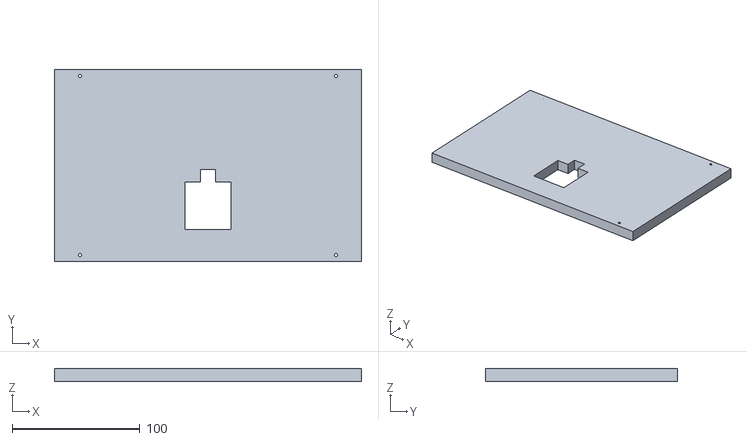
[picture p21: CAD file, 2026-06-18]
POC/Enclosure/POC/STL/topcover.stl
240.0 x 150.0 x 10.0

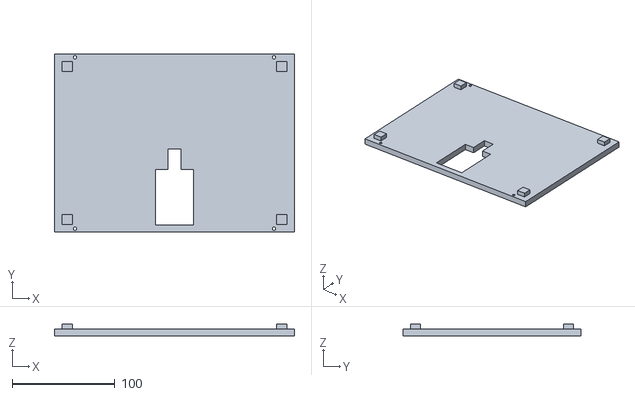
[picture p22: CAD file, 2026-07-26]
Final/Enclosure/STL/top.stl
234.0 x 174.0 x 12.0

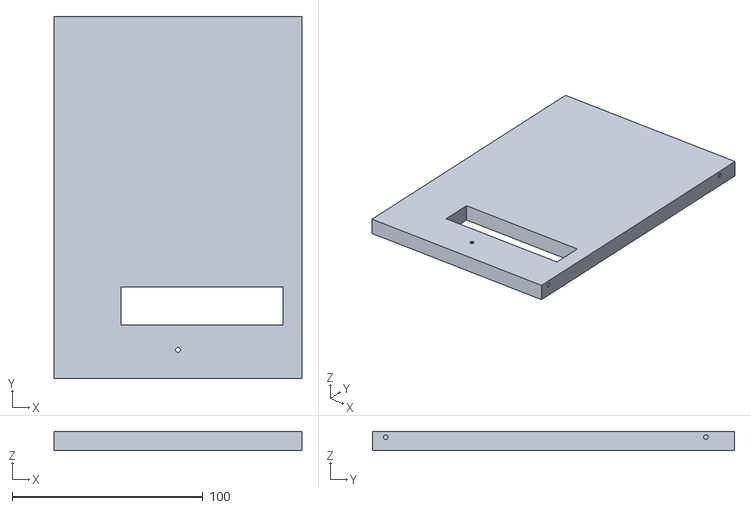
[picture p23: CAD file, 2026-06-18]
POC/Enclosure/POC/STL/rightwall.stl
130.0 x 190.0 x 10.00

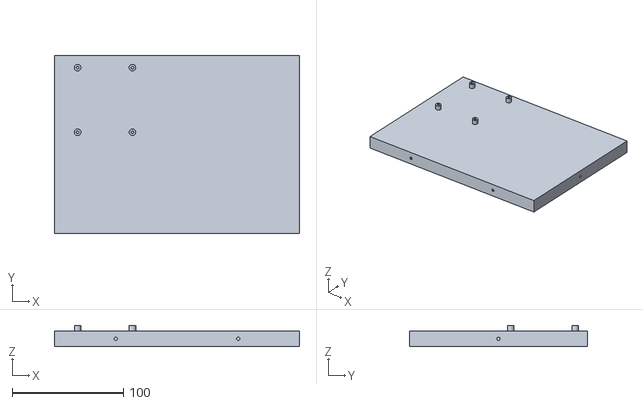
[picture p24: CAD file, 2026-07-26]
Final/Enclosure/STL/base.stl
220.0 x 160.0 x 19.0

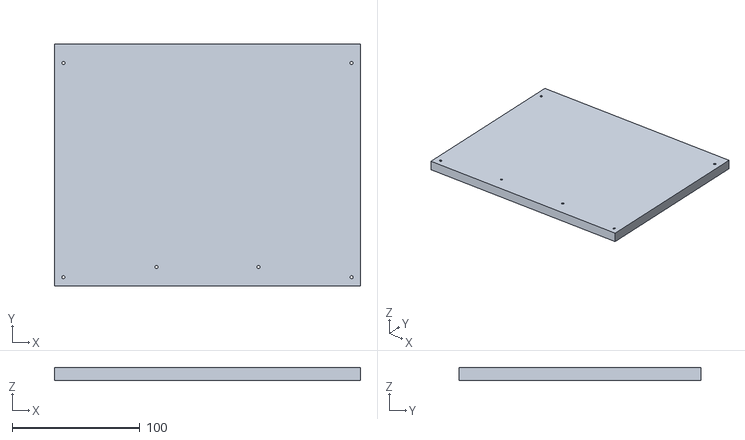
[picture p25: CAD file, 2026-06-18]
POC/Enclosure/POC/STL/back.stl
240.0 x 190.0 x 10.00

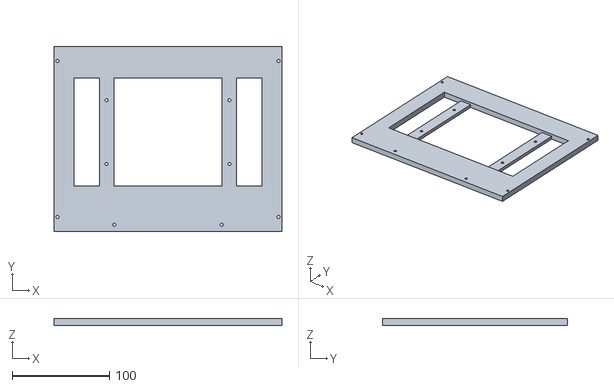
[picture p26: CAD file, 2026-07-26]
Final/Enclosure/STL/front-wall.stl
234.0 x 190.0 x 7.00

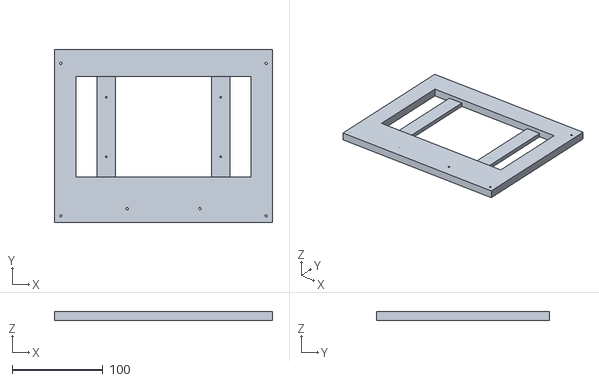
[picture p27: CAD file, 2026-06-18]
POC/Enclosure/POC/STL/front.stl
240.0 x 190.0 x 10.00

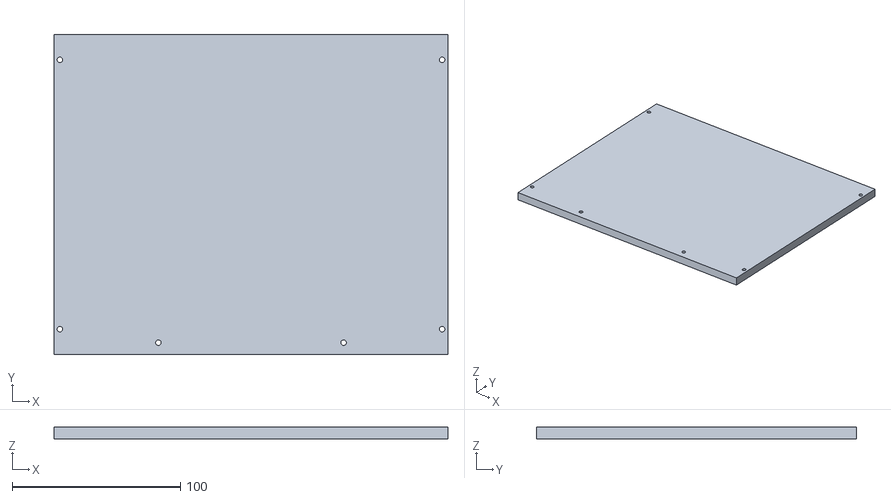
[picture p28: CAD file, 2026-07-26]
Final/Enclosure/STL/back-wall.stl
234.0 x 190.0 x 7.00

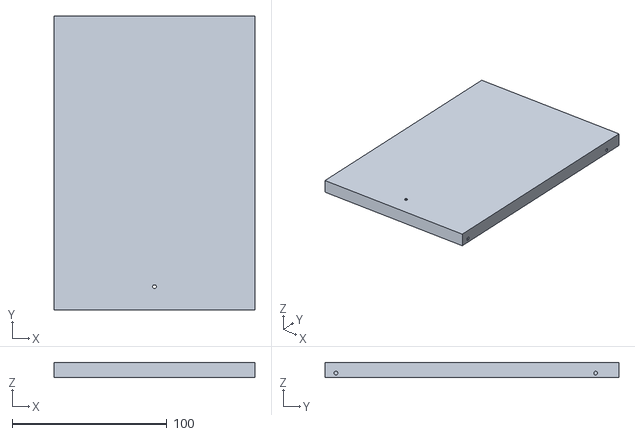
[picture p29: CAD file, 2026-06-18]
POC/Enclosure/POC/STL/leftwall.stl
130.0 x 190.0 x 10.00

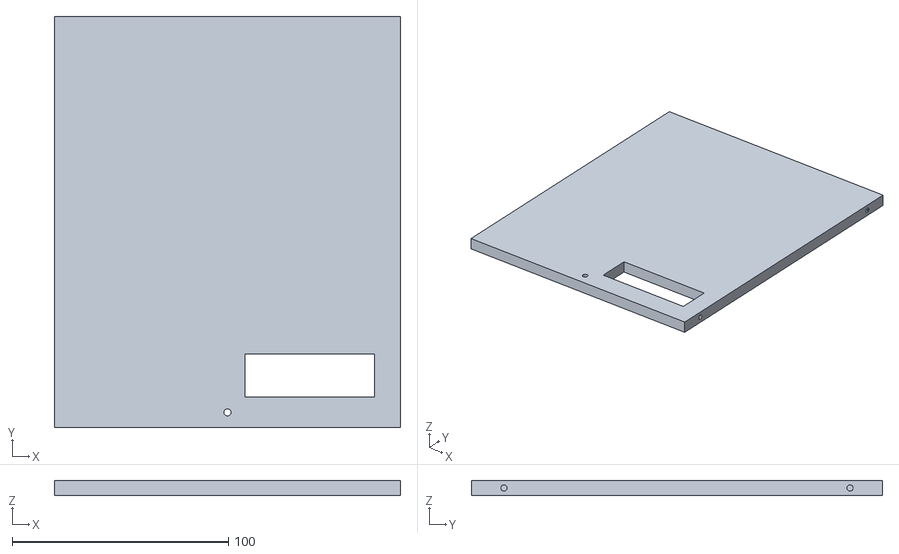
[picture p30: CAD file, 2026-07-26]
Final/Enclosure/STL/side-wall-with-hole.stl
160.0 x 190.0 x 7.00

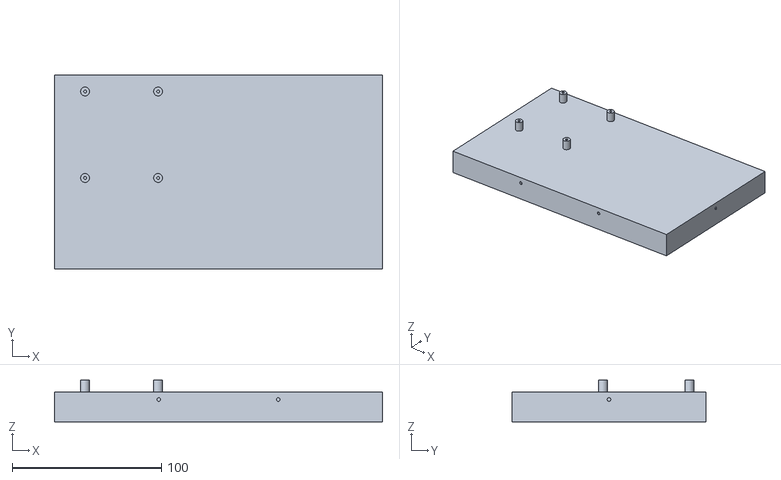
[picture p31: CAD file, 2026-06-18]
POC/Enclosure/POC/STL/base.stl
220.0 x 130.0 x 28.0

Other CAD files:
Final/Enclosure/CAD/top_cover.dwg
Final/Enclosure/CAD/back_and_front_wall.dwg
Final/Enclosure/CAD/base_(updated).dwg
Final/Enclosure/CAD/side_walls.dwg
POC/Enclosure/POC/CAD/back.dwg
POC/Enclosure/POC/CAD/base.dwg
POC/Enclosure/POC/CAD/front.dwg
POC/Enclosure/POC/CAD/leftwall.dwg
POC/Enclosure/POC/CAD/rightwall.dwg
POC/Enclosure/POC/CAD/topcover.dwg

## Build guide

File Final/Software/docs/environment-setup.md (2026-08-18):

# Environment Setup

Full from-scratch setup for running this on a blank Raspberry Pi. If you just want the short version, see the [Software README](../README.md) — this page is for actually recreating the environment, including the parts that aren't obvious from the code alone.

## 1. Operating system

**Raspberry Pi OS**, with the display running **X11, not Wayland**. Some Pi setups default to Wayland, which caused real, hard-to-diagnose touchscreen problems during development (touch position tracked correctly, but taps didn't register as clicks — a classic symptom of this specific mismatch).

Check which one you're on:
```bash
echo $XDG_SESSION_TYPE
```
Should say `x11`. If it says `wayland`:
```bash
sudo raspi-config
```
→ Advanced Options → Wayland → X11 → reboot.

## 2. Python environment (conda)

This project runs inside a **conda environment**, not the system Python — this matters, because installing dependencies into the wrong Python environment is one of the most common reasons a "correctly installed" setup still doesn't run.

```bash
conda create -n photobooth_usb python=3.11
conda activate photobooth_usb
```

*(If you're picking up this project on a Pi where the environment already exists, just `conda activate photobooth_usb` — check `conda env list` if you're not sure it's there.)*

With the environment active, install dependencies — see [dependencies.md](./dependencies.md) for what each one is for:
```bash
pip install -r requirements.txt --break-system-packages
```

## 3. Folder layout

The app expects to live in its own folder (e.g. `~/photobooth/`), with `finalphotobooth.py` and `style.py` side by side — `style.py` is imported directly by the main file, so it has to be in the same folder, not just installed as a package.

Background images go in `assets/backgrounds/` inside that same folder — see [background-templates.md](./background-templates.md).

## 4. Camera

The app expects the webcam at `/dev/video0` (the `CAMERA_DEVICE` constant near the top of `finalphotobooth.py`). Plug in the USB webcam and confirm it shows up there before running the app:
```bash
ls /dev/video0
```
If it's missing right after boot, wait ~30 seconds — some Pi setups need a moment for USB devices to finish initializing, and launching the app too early can cause camera errors that a short wait resolves on its own.

## 5. Speaker (GPIO)

Wire the speaker's Signal pin to GPIO 18 (BCM numbering — physical pin 12), with GND and VCC connected normally. The app is written to keep working with no sound at all if the speaker isn't connected or `RPi.GPIO` isn't installed, so this isn't a hard blocker to get running — just confirm the wiring against `SPEAKER_PIN` in the code if you expect sound and aren't getting any.

## 6. rclone (for photo uploads)

Install `rclone` itself (this is a separate system tool, not a Python package — see [rclone.org](https://rclone.org)), then configure a remote once:
```bash
rclone config
```
Follow the prompts to connect a Google Drive account. The remote name you choose needs to match `RCLONE_REMOTE` near the top of `finalphotobooth.py` (currently set to `gdrive`) — if you name it something else, either update the code to match or rename the remote.

## 7. Running it

With the conda environment active:
```bash
DISPLAY=:0 python3 finalphotobooth.py
```

The `DISPLAY=:0` is important if you're launching from a script, a terminal session that isn't the Pi's own desktop session, or over SSH — without it, the app can fail to find a display to draw the GUI on at all, even though everything else is set up correctly.

## What to expect on first launch

The first run will take noticeably longer than normal — the YOLO model gets downloaded and converted to a faster format (ONNX) automatically the first time, which only happens once. Subsequent launches are much quicker.

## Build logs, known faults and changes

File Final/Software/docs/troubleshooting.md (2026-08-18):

# Known Issues & Troubleshooting

This page covers real problems encountered during development, how they were diagnosed, and their current status — split into things that are genuinely fixed, and things that are known limitations rather than bugs waiting to be found.

## Fixed issues

**Touchscreen registered movement but not taps.** Traced to the Pi's display running Wayland instead of X11 — a display-server-level setting, not an app bug. Fixed by switching to X11 via `raspi-config`. See [environment-setup.md](./environment-setup.md).

**Some text on screen had visibly broken/missing characters (most noticeably the letter "i").** Traced to several on-screen labels having a font hardcoded directly in the code (`"Arial"`) which, on this Linux system, doesn't reliably map to a complete, well-behaved font — while other labels correctly used the app's actual configured font (DejaVu Sans) and rendered fine. Fixed by making every label consistently use the same properly-configured font.

**The Pi's clock drifts, breaking secure connections.** The school network blocks the standard internet time-sync protocol (NTP), so the Pi's clock can become inaccurate after being powered off for a while, which in turn can break the secure connection needed to upload photos (secure connections check the current date against a certificate's valid dates). Fixed by having the app correct the clock automatically at every startup, using an alternative method (reading the time from a normal, unblocked web request) instead of the blocked one.

**The camera would intermittently hang or fail during capture.** This was the largest single problem in the project — see [camera-reliability.md](./camera-reliability.md) for the full account of what was tried and what actually fixed it.

**The app would occasionally freeze entirely (not just the camera) with no visible cause.** Traced to slow operations (camera reads, photo processing, uploads) running directly on the same thread responsible for drawing the screen. Fixed by moving all of these onto background threads — see [architecture.md](./architecture.md).

## Known, accepted limitations (not bugs — deliberate trade-offs)

**Final photos are 1080p, not a higher resolution.** A deliberate trade-off made to fix the camera reliability issue above — see [camera-reliability.md](./camera-reliability.md) for the reasoning.

**Very light-coloured clothing (e.g. a white shirt) can be a soft spot for the background-removal quality**, depending on the specific background and lighting. This is a genuine, known limitation of the segmentation approach described in [pipeline-explained.md](./pipeline-explained.md), not something that was overlooked.

**If the background upload service fails once, nothing forces it back to a working state — but that doesn't mean it's guaranteed to stay broken either.** There's no explicit auto-restart logic, by deliberate design (a more complex version with exactly that was built, tested, and dropped for being less stable), but the service can still recover on its own if the underlying cause was transient rather than fatal. Every upload still succeeds regardless, via the fallback path when needed — this is the exact behaviour used in the final presentation. See [download-pipeline.md](./download-pipeline.md) for the full reasoning.

## If something looks broken that isn't listed here

Check the terminal output the app is running in — it prints a running log of what's happening (camera status, processing timings, upload status, and any errors), which is almost always the fastest way to tell what's actually going on versus guessing from the screen alone.

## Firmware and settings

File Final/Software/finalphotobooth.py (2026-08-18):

import os
import cv2
import time
import shutil
import zipfile
import threading
import json
import urllib.request
import urllib.error
import subprocess
import tkinter as tk
from tkinter import Label, Button
from datetime import datetime

import qrcode
import mediapipe as mp
import numpy as np
from PIL import Image, ImageTk, ImageDraw, ImageFont

try:
    from ultralytics import YOLO
    YOLO_AVAILABLE = True
except ImportError:
    YOLO_AVAILABLE = False

try:
    import RPi.GPIO as GPIO
    GPIO_AVAILABLE = True
except ImportError:
    GPIO_AVAILABLE = False

from style import (
    BG_COLOR,
    PANEL_COLOR,
    TEXT_COLOR,
    MUTED_TEXT_COLOR,
    SELECTED_COLOR,
    BUTTON_DARK,
    BUTTON_TEXT,
    CAPTURE_COLOR,
    CONFIRM_COLOR,
    RETAKE_COLOR,
    PREVIEW_BG,
    TITLE_FONT,
    SECONDARY_FONT,
    LABEL_FONT,
    BUTTON_FONT,
    BIG_BUTTON_FONT,
)


# ============================================================
# SETTINGS
# ============================================================

BASE_DIR = os.path.dirname(os.path.abspath(__file__))
BACKGROUND_DIR = os.path.join(BASE_DIR, "assets", "backgrounds")
SAVE_FOLDER = os.path.join(BASE_DIR, "saved_images")
QR_SAVE_DIR = os.path.join(BASE_DIR, "qrcodes")

os.makedirs(BACKGROUND_DIR, exist_ok=True)
os.makedirs(SAVE_FOLDER, exist_ok=True)
os.makedirs(QR_SAVE_DIR, exist_ok=True)

# rclone remote must already be configured (rclone config) — change these two
# to match what you set up when you tested with test.txt.
RCLONE_REMOTE = "gdrive"
RCLONE_REMOTE_FOLDER = "Photobooth"

# rclone runs as a persistent background daemon (rcd) instead of a fresh
# CLI process per operation - this is what actually fixes the "seesaw"
# copy/link timing found during testing (e.g. 54s vs 4s for the same
# operation, run seconds apart): each fresh CLI process independently
# gambled on connection/OAuth-token setup, while the daemon negotiates
# once at startup and reuses that same warm connection for every
# operation afterward.
RCLONE_RC_PORT = 5572

CAMERA_DEVICE = "/dev/video0"

# Live preview feed resolution (continuous, needs to stay smooth)
CAPTURE_WIDTH = 1920
CAPTURE_HEIGHT = 1080

OUTPUT_WIDTH = 1920
OUTPUT_HEIGHT = 1080

# Event banner - drawn as a third layer ON TOP of the finished person+
# background composite, not baked into the background image itself, so
# it's never blocked by whoever's standing in the shot.
EVENT_BANNER_TEXT = "Project Phantom @ NYP S.536"
EVENT_DATE_FORMAT = "%d %B %Y"  # e.g. "19 August 2026" - always TODAY's date, not hardcoded
EVENT_BANNER_OPACITY = 0.6  # 0 = invisible, 1 = fully opaque black strip
EVENT_BANNER_FONT_PATH = "/usr/share/fonts/truetype/dejavu/DejaVuSans-Bold.ttf"
EVENT_DATE_FONT_PATH = "/usr/share/fonts/truetype/dejavu/DejaVuSans.ttf"  # regular weight, not bold - keeps the date visually secondary to the title

# Custom-designed graphic overlay (OBS-style) - if this file exists, it's
# used INSTEAD of the plain banner above, with the date still drawn live
# on top at EVENT_DATE_POSITION. If it doesn't exist yet, falls back to
# the plain banner automatically - nothing breaks if no time to design.
EVENT_GRAPHIC_PATH = os.path.join(BASE_DIR, "assets", "event_overlay.png")
EVENT_DATE_POSITION = (OUTPUT_WIDTH // 2, OUTPUT_HEIGHT - 40)  # (x, y) - CENTER of the text, adjust once the real design exists
EVENT_DATE_FONT_SIZE = 28
EVENT_DATE_COLOR = (255, 255, 255)  # RGB

# LOCAL CLEANUP - no timers at all. saved_images/ and qrcodes/ get wiped
# completely (deleted and recreated empty) at both app STARTUP and
# SHUTDOWN via wipe_output_folders() - simpler than per-session timed
# deletion, and crash-proof by construction: even if the app never reaches
# a clean shutdown, the next startup wipes stale content before the new
# run begins. Google Drive is left alone entirely - cleaned up manually.

# DFRobot Gravity 8002 Digital Speaker - wired GND/VCC/Signal, Signal to
# this GPIO pin (BCM numbering, physical pin 12). Driven like an Arduino
# buzzer: toggling this pin at an audio frequency, not playing audio files.
SPEAKER_PIN = 18

# If the background camera reader thread claims to be running but hasn't
# produced a real frame in this many seconds, treat it as stuck (not
# just slow) and abandon it rather than trust the "running" flag, which
# can't tell the difference on its own - see start_camera().
STALE_FRAME_THRESHOLD = 3.0

# Reserved height for the top settings bar, subtracted from preview budgets
# below so nothing overlaps it.
TOP_BAR_HEIGHT = 34

# YOLO detection box expansion - how much padding (as a fraction of box
# width/height) to add before cropping and feeding to MediaPipe, so hair
# sticking up past the box or feet right at the edge don't get clipped.
BOX_MARGIN_FRACTION = 0.18

# MediaPipe mask tuning (same as V3's original soft-alpha approach, now
# applied per-person-crop instead of the full frame).
ALPHA_LOW = 0.28
ALPHA_HIGH = 0.75

# Focused hair-region matting refinement (on top of each person's already
# fast MediaPipe crop mask). The refined region is found adaptively from
# where MediaPipe's own mask is uncertain (see get_uncertain_region_bbox),
# not a fixed fraction - this is what makes it work regardless of hair
# length/style rather than assuming a fixed proportion of the crop.

# Matting never fully replaces the landscape model's original alpha -
# this caps how much weight the refinement can have (1.0 = full
# replacement, lower = blended with the original as a safety net). The
# general model is more permissive/soft than landscape, which is exactly
# why it's better at hair - but that same softness can occasionally
# over-include background under harsh/uneven lighting. A partial blend
# limits how much a bad call there can affect the result, without giving
# up the improvement when it gets it right.
MATTING_BLEND_STRENGTH = 0.7


class PhotoboothApp:
    def __init__(self, root):
        self.root = root
        self.root.title("Photobooth")
        self.root.configure(bg=BG_COLOR)
        self.root.attributes("-fullscreen", True)

        # Force 1:1 pixel scaling. Some Raspberry Pi OS + touchscreen setups
        # leave Tk's internal scaling factor mismatched with the real display,
        # which shows up as touches only registering near a button's exact
        # center instead of anywhere on it. If buttons are still imprecise
        # after this, the mismatch is likely at the touchscreen driver level
        # (see the note below).
        self.root.tk.call("tk", "scaling", 1.0)

        self.screen_w = self.root.winfo_screenwidth()
        self.screen_h = self.root.winfo_screenheight()

        self.cap = None
        self.preview_running = False
        self.countdown_number = None
        self.camera_released_at = None  # set by stop_camera(), used to guarantee a minimum gap before reopening
        self.camera_thread = None
        self.camera_thread_running = False
        self.camera_frame_lock = threading.Lock()
        self.latest_frame_raw = None  # most recent frame from the background reader thread
        self.last_frame_time = None  # when that frame actually arrived - used to detect a stuck reader thread
        self.live_screen_active = False  # True only while the live screen's widgets actually exist

        self.current_frame = None      # full-resolution camera frame
        self.captured_frame = None     # full-resolution still photo

        self.tk_preview_image = None
        self.tk_result_image = None

        self.backgrounds = self.load_backgrounds()

        self.session_folder = None
        self.output_files = []
        self.selected_outputs = set()
        self.gallery_index = 0

        # Wipe local outputs from any previous run before this one starts -
        # see the LOCAL CLEANUP comment near the top of the file.
        self.wipe_output_folders()

        # rclone daemon - started once here, reused for every download all
        # session, instead of a fresh CLI process (and fresh connection
        # negotiation) per copy/link call. See RCLONE_RC_PORT comment.
        self.rclone_daemon_process = None
        self.rclone_keepalive_running = False
        try:
            self.rclone_daemon_process = subprocess.Popen(
                [
                    "rclone", "rcd", "--rc-no-auth", f"--rc-addr=localhost:{RCLONE_RC_PORT}",
                    "--contimeout", "15s",
                    "--timeout", "15s",
                ],
                stdout=subprocess.DEVNULL,
                stderr=subprocess.DEVNULL,
            )
            daemon_ready = False
            for _ in range(20):  # up to ~5 seconds, polling rather than a blind sleep
                try:
                    self.rclone_rc_call("core/version", {}, timeout=2)
                    daemon_ready = True
                    break
                except Exception:
                    time.sleep(0.25)
            if daemon_ready:
                print("rclone daemon ready on port", RCLONE_RC_PORT)
                # Periodic no-op call to keep the underlying connection to
                # Drive from going idle-stale (a real thing regardless of
                # wifi power-save specifically - TCP connections can be
                # dropped by the router/OS/Drive's own end after enough
                # idle time, independent of the radio's own sleep state).
                self.rclone_keepalive_running = True
                threading.Thread(target=self.rclone_keepalive_loop, daemon=True).start()
            else:
                print("rclone daemon did not become ready in time - downloads may fail")
        except Exception as e:
            print("Failed to start rclone daemon:", e)
            self.rclone_daemon_process = None

        # Speaker setup - once at startup (accepted small startup-time
        # cost), wrapped in try/except so a missing/failed speaker never
        # breaks the app, just plays no sound.
        self.speaker_available = False
        if GPIO_AVAILABLE:
            try:
                GPIO.setmode(GPIO.BCM)
                GPIO.setup(SPEAKER_PIN, GPIO.OUT)
                self.speaker_available = True
                print("Speaker ready on GPIO", SPEAKER_PIN)
            except Exception as e:
                print("Speaker setup failed, continuing without sound:", e)
                self.speaker_available = False
        else:
            print("RPi.GPIO not installed - continuing without sound")

        # MediaPipe kept loaded as a safety-net fallback - if YOLO fails to
        # install, load, or errors on a specific photo, the app degrades to
        # this known-working hard cutout instead of failing outright. This
        # matters because the YOLO pipeline below hasn't been tested on
        # real hardware yet.
        self.mp_selfie = mp.solutions.selfie_segmentation
        self.segmenter = self.mp_selfie.SelfieSegmentation(model_selection=1)

        # Primary detection: plain YOLO11n (boxes only, not the -seg
        # variant - we only need bounding boxes here, MediaPipe does the
        # actual per-person masking on each crop). Trained on general
        # multi-person photos (COCO), not selfie/video-call framing - the
        # bet here is that generalizes better to distant, multi-person,
        # non-centered group shots for LOCATING people. Exported to ONNX
        # once at startup for CPU inference speed.
        self.yolo_model = None
        if YOLO_AVAILABLE:
            try:
                base_model = YOLO("yolo11n.pt")
                onnx_path = base_model.export(format="onnx")
                self.yolo_model = YOLO(onnx_path)
                print("YOLO11n loaded (ONNX)")
            except Exception as e:
                print("YOLO failed to load, falling back to MediaPipe:", e)
                self.yolo_model = None
        else:
            print(
                "ultralytics not installed - falling back to MediaPipe. "
                "Run: pip install ultralytics --break-system-packages"
            )

        # Second MediaPipe segmenter, model_selection=0 (general/selfie),
        # used ONLY for hair-region refinement. Your own A/B test on a real
        # YOLO crop showed general is noticeably better around hair, but
        # lets more background through elsewhere on the body - so it's
        # confined to small hair/hand crops here, same as the rembg
        # variant was, rather than replacing the body's landscape model.
        self.mp_selfie_general = mp.solutions.selfie_segmentation
        self.segmenter_general = self.mp_selfie_general.SelfieSegmentation(model_selection=0)

        self.root.bind("<Escape>", lambda event: self.close_app())

        self.show_live_screen()

    # ============================================================
    # BASIC HELPERS
    # ============================================================

    def clear_screen(self):
        self.live_screen_active = False
        for widget in self.root.winfo_children():
            widget.destroy()

    def fit_16_9(self, max_w, max_h):
        """Return the largest 16:9 size that fits within max_w x max_h."""
        target_ratio = 16 / 9

        w = int(max_w)
        h = int(w / target_ratio)

        if h > max_h:
            h = int(max_h)
            w = int(h * target_ratio)

        return max(1, w), max(1, h)

    def frame_to_tk(self, frame_bgr, max_w, max_h, selected=False):
        """Convert BGR frame to resized Tk image."""
        display_w, display_h = self.fit_16_9(max_w, max_h)

        if selected:
            # Small pop-out effect for selected gallery image
            display_w = min(int(display_w * 1.03), int(max_w))
            display_h = min(int(display_h * 1.03), int(max_h))

        display_frame = cv2.resize(
            frame_bgr,
            (display_w, display_h),
            interpolation=cv2.INTER_AREA,
        )
        display_rgb = cv2.cvtColor(display_frame, cv2.COLOR_BGR2RGB)

        image = Image.fromarray(display_rgb)
        return ImageTk.PhotoImage(image=image)

    def load_backgrounds(self):
        valid_ext = (".jpg", ".jpeg", ".png")

        files = [
            os.path.join(BACKGROUND_DIR, f)
            for f in os.listdir(BACKGROUND_DIR)
            if f.lower().endswith(valid_ext)
        ]

        files.sort()

        if not files:
            print("No backgrounds found in:", BACKGROUND_DIR)

        return files

    def safe_name(self, path):
        name = os.path.splitext(os.path.basename(path))[0].lower()
        cleaned = "".join(c if c.isalnum() else "_" for c in name)
        cleaned = cleaned.strip("_")
        return cleaned or "background"

    def make_button(
        self,
        parent,
        text,
        command,
        bg,
        fg="black",
        width=12,
        height=2,
        font=None,
        pad_y=4,
        pad_x=0,
    ):
        return Button(
            parent,
            text=text,
            command=command,
            font=font or BUTTON_FONT,
            width=width,
            height=height,
            pady=pad_y,
            padx=pad_x,
            bg=bg,
            fg=fg,
            activebackground=bg,
            activeforeground=fg,
            relief="flat",
            bd=0,
            highlightthickness=0,
        )

    def build_top_bar(self, left_text=""):
        """Consistent top bar used on every screen: optional centered
        status/position text and the settings button on the right, always
        at the same height/position - this is what makes button
        positioning consistent across the whole app rather than each
        screen improvising its own layout.

        Returns (bar_frame, center_label) - center_label is None if
        left_text was empty; callers can .config(text=...) it later.
        """
        bar = tk.Frame(self.root, bg=BG_COLOR, height=TOP_BAR_HEIGHT)
        bar.pack(side="top", fill="x")
        bar.pack_propagate(False)

        center_label = None
        if left_text:
            center_label = Label(
                bar,
                text=left_text,
                font=LABEL_FONT,
                fg=MUTED_TEXT_COLOR,
                bg=BG_COLOR,
            )
            center_label.place(relx=0.5, rely=0.5, anchor="center")

        settings_btn = Button(
            bar,
            text="SETTINGS",
            command=self.open_settings_popup,
            font=("DejaVu Sans", 10, "bold"),
            bg=BUTTON_DARK,
            fg=BUTTON_TEXT,
            relief="flat",
            bd=0,
            highlightthickness=0,
            padx=8,
            pady=4,
        )
        settings_btn.pack(side="right", padx=8, pady=4)

        return bar, center_label


    def show_alert_popup(self, message):
        """Prominent popup for messages the user needs to actually notice
        (e.g. 'select at least one image') - bigger and more attention-
        grabbing than a small status-label flash."""
        popup = tk.Toplevel(self.root)
        popup.configure(bg=PANEL_COLOR)
        popup.overrideredirect(True)
        popup.attributes("-topmost", True)

        popup_w, popup_h = 480, 260
        x = (self.screen_w - popup_w) // 2
        y = (self.screen_h - popup_h) // 2
        popup.geometry(f"{popup_w}x{popup_h}+{x}+{y}")

        message_label = Label(
            popup,
            text=message,
            font=SECONDARY_FONT,
            fg=TEXT_COLOR,
            bg=PANEL_COLOR,
            wraplength=popup_w - 60,
            justify="center",
        )
        message_label.pack(expand=True, pady=(20, 10))

        ok_btn = self.make_button(
            popup,
            text="OK",
            command=popup.destroy,
            bg=CAPTURE_COLOR,
            fg="black",
            width=18,
            height=1,
            font=BUTTON_FONT,
            pad_y=8,
        )
        ok_btn.pack(pady=(0, 20))

    def open_settings_popup(self):
        popup = tk.Toplevel(self.root)
        popup.configure(bg=PANEL_COLOR)
        popup.overrideredirect(True)
        popup.attributes("-topmost", True)

        popup_w, popup_h = 340, 240
        x = (self.screen_w - popup_w) // 2
        y = (self.screen_h - popup_h) // 2
        popup.geometry(f"{popup_w}x{popup_h}+{x}+{y}")

        # Grouped so it centers as one block, rather than sitting at the
        # top of the popup.
        content = tk.Frame(popup, bg=PANEL_COLOR)
        content.pack(expand=True)

        title = Label(
            content,
            text="Settings",
            font=TITLE_FONT,
            fg=TEXT_COLOR,
            bg=PANEL_COLOR,
        )
        title.pack(pady=(0, 12))

        end_btn = self.make_button(
            content,
            text="END PROGRAM",
            command=self.close_app,
            bg="#D9534F",
            fg="white",
            width=18,
            height=1,
            font=BUTTON_FONT,
            pad_y=8,
        )
        end_btn.pack(pady=4)

        close_btn = self.make_button(
            content,
            text="CLOSE",
            command=popup.destroy,
            bg=BUTTON_DARK,
            fg=BUTTON_TEXT,
            width=18,
            height=1,
            font=BUTTON_FONT,
            pad_y=8,
        )
        close_btn.pack(pady=6)

    # ============================================================
    # CAMERA
    # ============================================================

    def start_camera(self, force_reopen=False):
        """Opens the camera and starts a background thread that
        continuously reads frames - reading happens OFF the main thread
        specifically because a slow/blocking camera read (the actual
        observed flakiness - can block for 10-40+ seconds INSIDE a single
        read call) would otherwise freeze the entire UI, including the
        loading spinner itself. update_preview() only ever polls whatever
        the background thread most recently read - it never blocks.

        If the camera is already open with its reader thread already
        running AND recently produced a real frame, does nothing and
        returns immediately - avoids an unnecessary close/reopen cycle
        (e.g. RETAKE going back to live preview, where the camera was
        never actually stopped).

        The "recently produced a frame" check matters on its own: a
        genuinely STUCK reader thread (a single cap.read() call that
        never returns - not just slow) still reports itself as "running"
        forever, since Python can't forcibly kill a thread blocked inside
        a C-level call. Trusting the flag alone would spin the loading
        indicator forever with no way to recover. Checking how long it's
        actually been since a real frame arrived is what catches this.
        """
        thread_claims_running = not force_reopen and self.cap is not None and self.camera_thread_running

        if thread_claims_running:
            frame_is_fresh = (
                self.last_frame_time is not None
                and (time.time() - self.last_frame_time) < STALE_FRAME_THRESHOLD
            )
            if frame_is_fresh:
                self.preview_running = True
                return True
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

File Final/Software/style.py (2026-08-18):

# style.py
# Final UX rebuild for EGL314 Photobooth
# Designed for 7-inch Raspberry Pi touchscreen

# Main colours
BG_COLOR = "#0E0F13"
PANEL_COLOR = "#171A21"
PREVIEW_BG = "#1B1D24"

TEXT_COLOR = "#F5F5F5"
MUTED_TEXT_COLOR = "#9CA3AF"

# Buttons
BUTTON_DARK = "#252833"
BUTTON_TEXT = "#FFFFFF"

CAPTURE_COLOR = "#2ECC71"
CONFIRM_COLOR = "#2ECC71"
RETAKE_COLOR = "#F5C542"

# Gallery selection
SELECTED_COLOR = "#F5C542"

# Fonts
# Titles/secondary/updates - non-button text
TITLE_FONT = ("DejaVu Sans", 24, "bold")
SECONDARY_FONT = ("DejaVu Sans", 18, "bold")
LABEL_FONT = ("DejaVu Sans", 10)
# Buttons - CAPTURE is the one deliberately biggest button in the app;
# every other button (including gallery RETAKE, which is smaller by
# container size, not font) shares this same uniform text size. The
# SETTINGS button uses its own small size, set directly where it's built.
BUTTON_FONT = ("DejaVu Sans", 16, "bold")
BIG_BUTTON_FONT = ("DejaVu Sans", 20, "bold")

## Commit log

2026-06-16 Revise README for EGL314 Photobooth Project
    Expanded the README to include project details, stages, and current status.
2026-07-26 MVP Documentation
    MVP documentation for Software
    [back.dwg, back.stl, base.dwg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]
2026-07-26 Rename back and front wall.dwg to back_and_front_wall.dwg
    [back_and_front_wall.dwg]
2026-07-26 Rename base (updated).dwg to base_(updated).dwg
    [base_(updated).dwg]
2026-07-26 Rename side walls.dwg to side_walls.dwg
    [side_walls.dwg]
2026-07-26 Rename top cover.dwg to top_cover.dwg
    [top_cover.dwg]
